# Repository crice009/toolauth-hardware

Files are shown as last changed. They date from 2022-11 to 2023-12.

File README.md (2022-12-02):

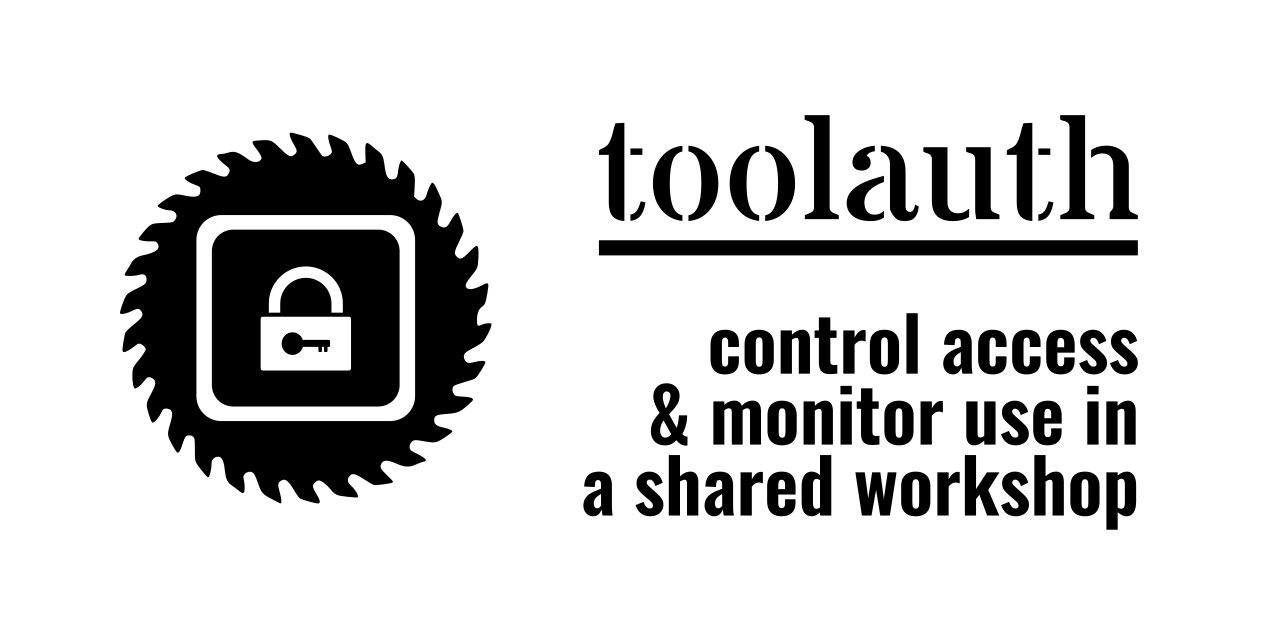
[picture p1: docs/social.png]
toolauth-logo


# toolauth-hardware
The custom PCB for the toolauth system. Intended to control access to tools (based on credentials) in a shared workshop. Designed to work with an ESP32 board and ESPHome.

Completely designed in KiCAD 6 and ordered as assembled boards from JLCPCB.

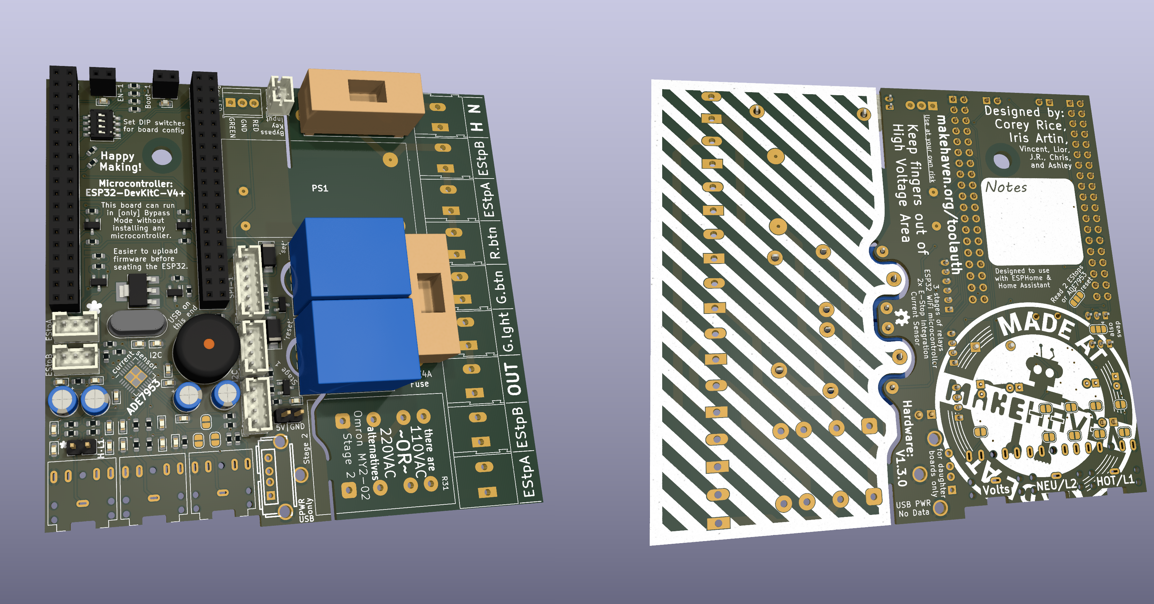
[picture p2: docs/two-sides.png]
board-examples board-renders


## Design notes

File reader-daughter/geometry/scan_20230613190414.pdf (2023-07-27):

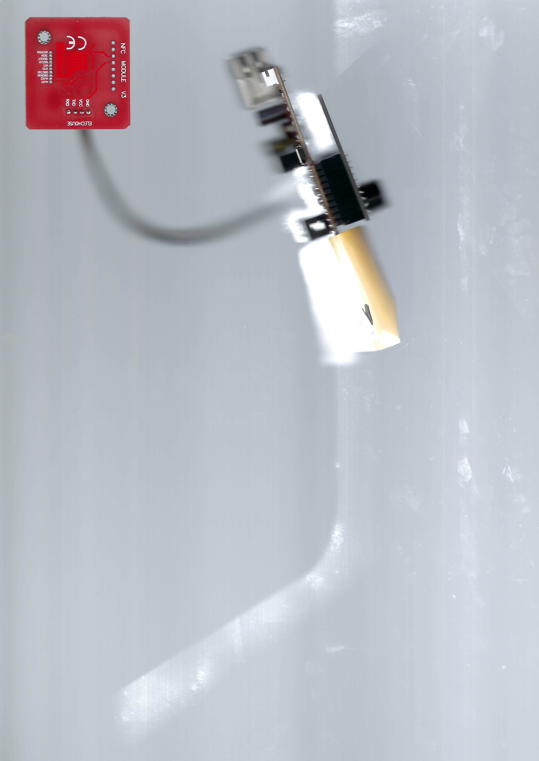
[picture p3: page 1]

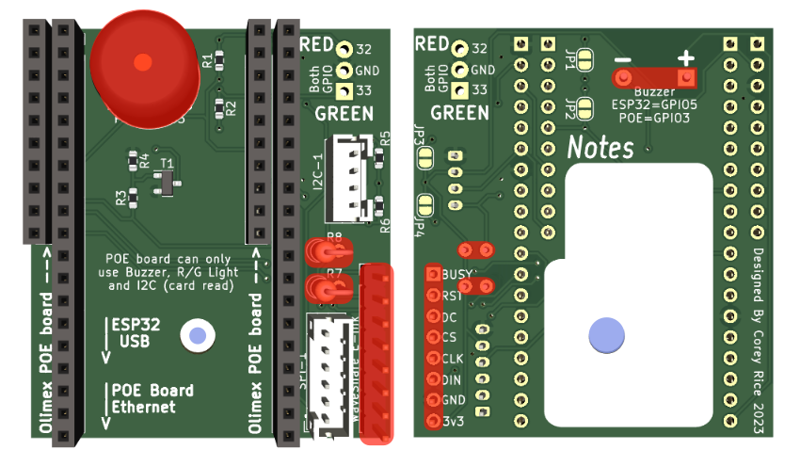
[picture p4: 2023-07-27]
docs/img/rd-design.png

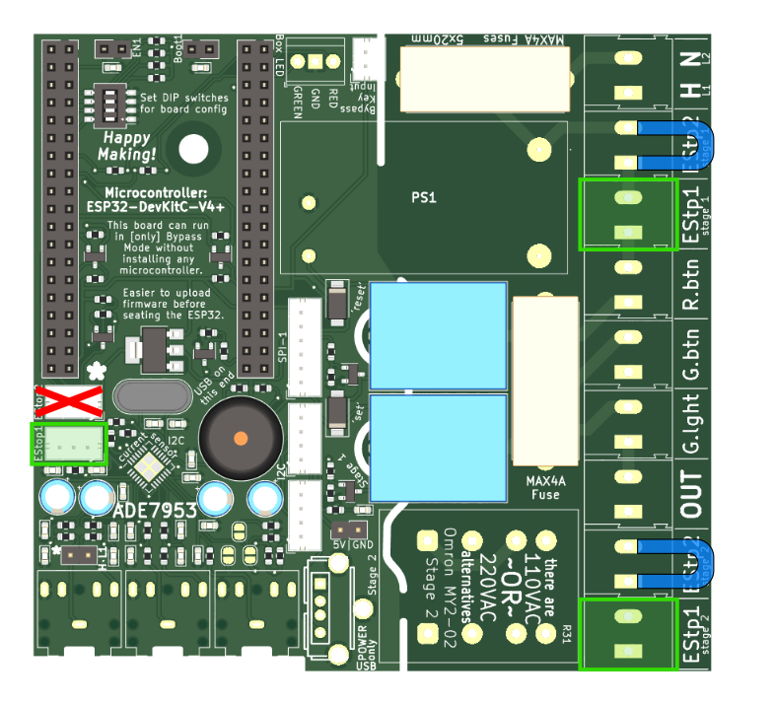
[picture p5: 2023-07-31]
docs/img/v1.3-one-estop.png

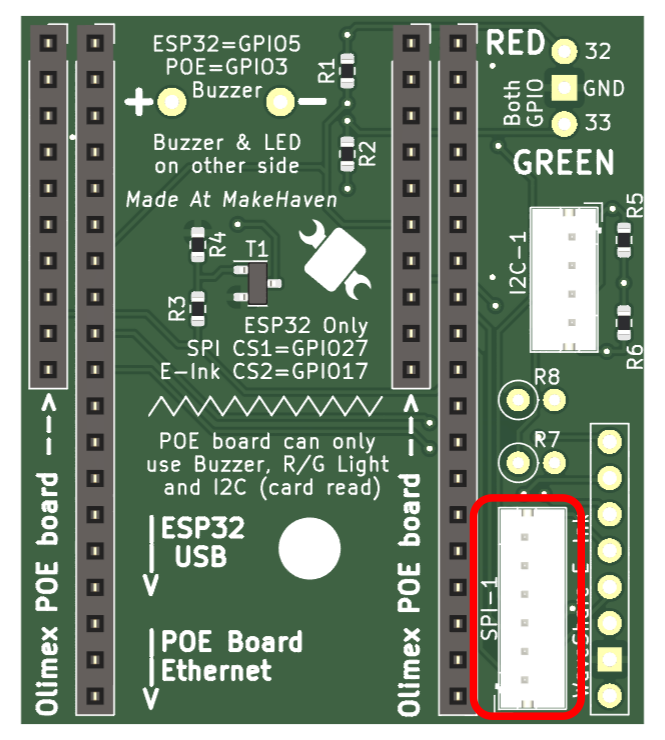
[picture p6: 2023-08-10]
docs/img/rd-spi.png

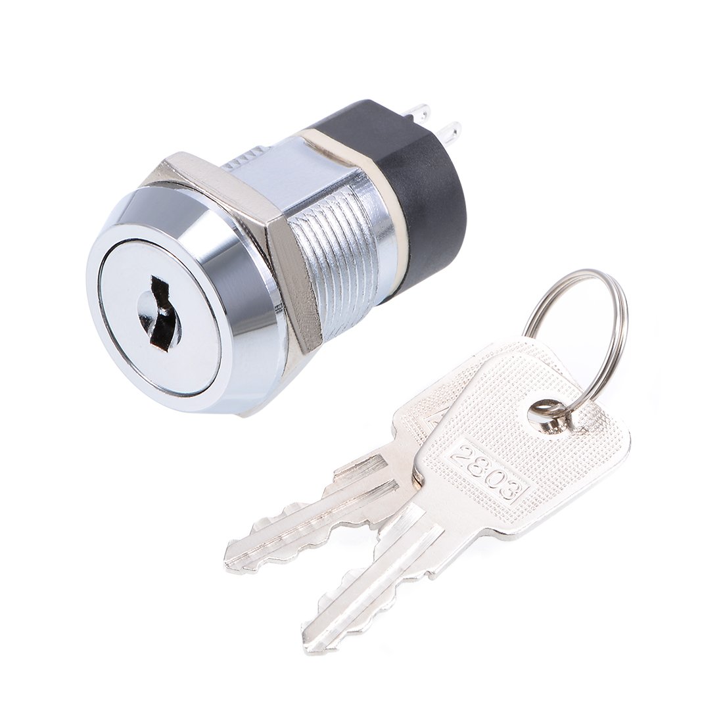
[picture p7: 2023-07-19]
docs/img/key-switch.jpg

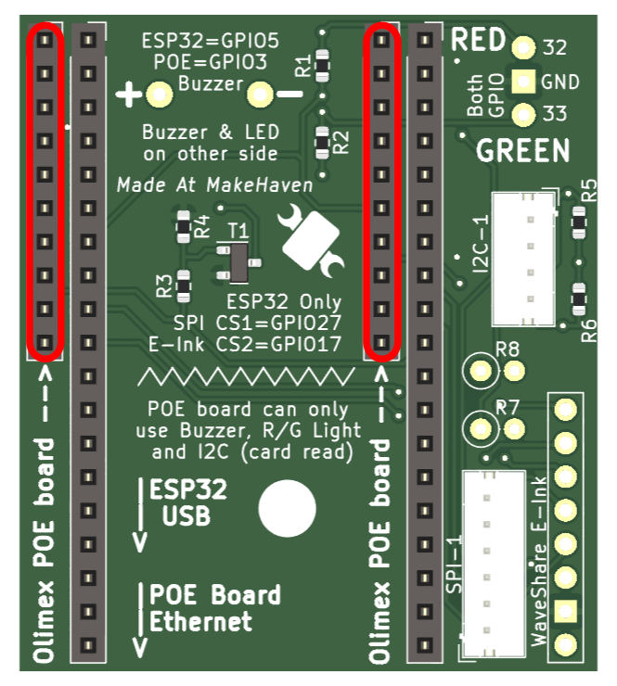
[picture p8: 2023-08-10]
docs/img/rd-poe.png

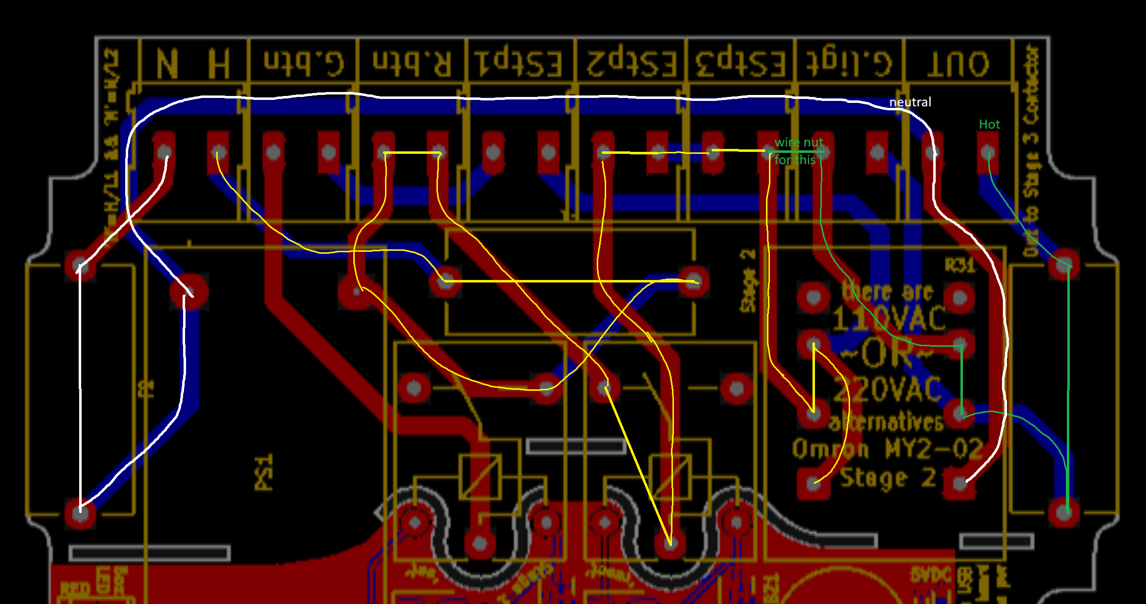
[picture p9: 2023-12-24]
docs/img/b1p2-gerber-markup.png

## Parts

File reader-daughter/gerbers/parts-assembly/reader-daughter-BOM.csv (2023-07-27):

Comment | Designator | Footprint | JLCPCB Part #
Conn_01x04_Female | I2C-1 | JST_PH_B4B-PH-K_1x04_P2.00mm_Vertical | C131334
1k | R2,R3,R1 | R_0603_1608Metric | C21190
Conn_01x06_Female | SPI-1 | JST_PH_B6B-PH-K_1x06_P2.00mm_Vertical | C131342
Conn_01x10_Female | J2,J1 | PinSocket_1x10_P2.54mm_Vertical | C358723
2.2k | R6,R5 | R_0603_1608Metric | C4190
Conn_01x19_Female | J6,J5 | PinSocket_1x19_P2.54mm_Vertical | C2897382
AO3400A | T1 | SOT-23 | C427382
10k | R4 | R_0603_1608Metric | C25804

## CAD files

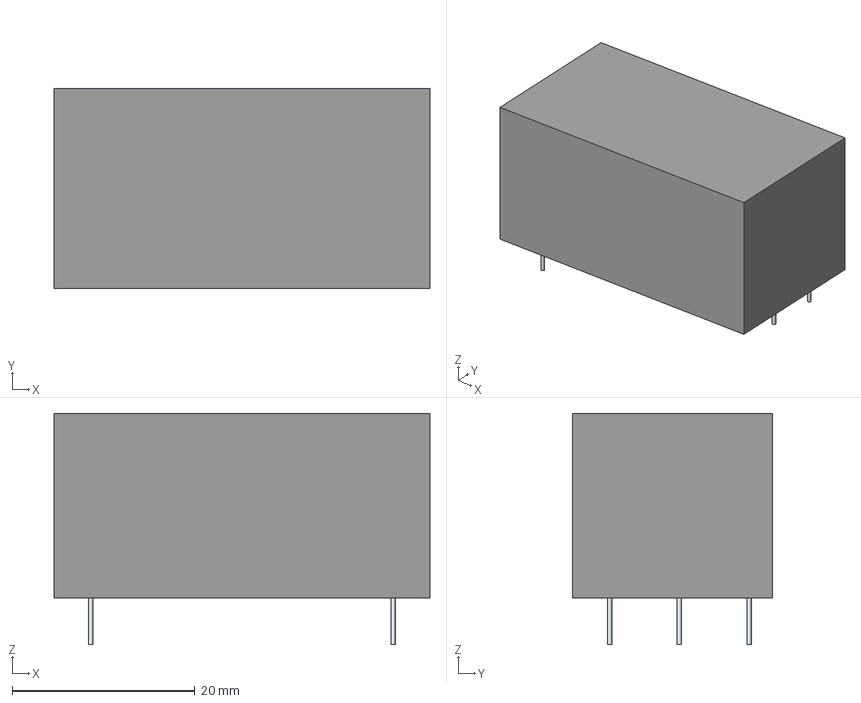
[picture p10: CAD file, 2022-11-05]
V1.3/odd-parts/CFM06S050-E-Cincon/CFM06S050-E.stp
41.1 x 21.8 x 25.3 mm
Leads x 4

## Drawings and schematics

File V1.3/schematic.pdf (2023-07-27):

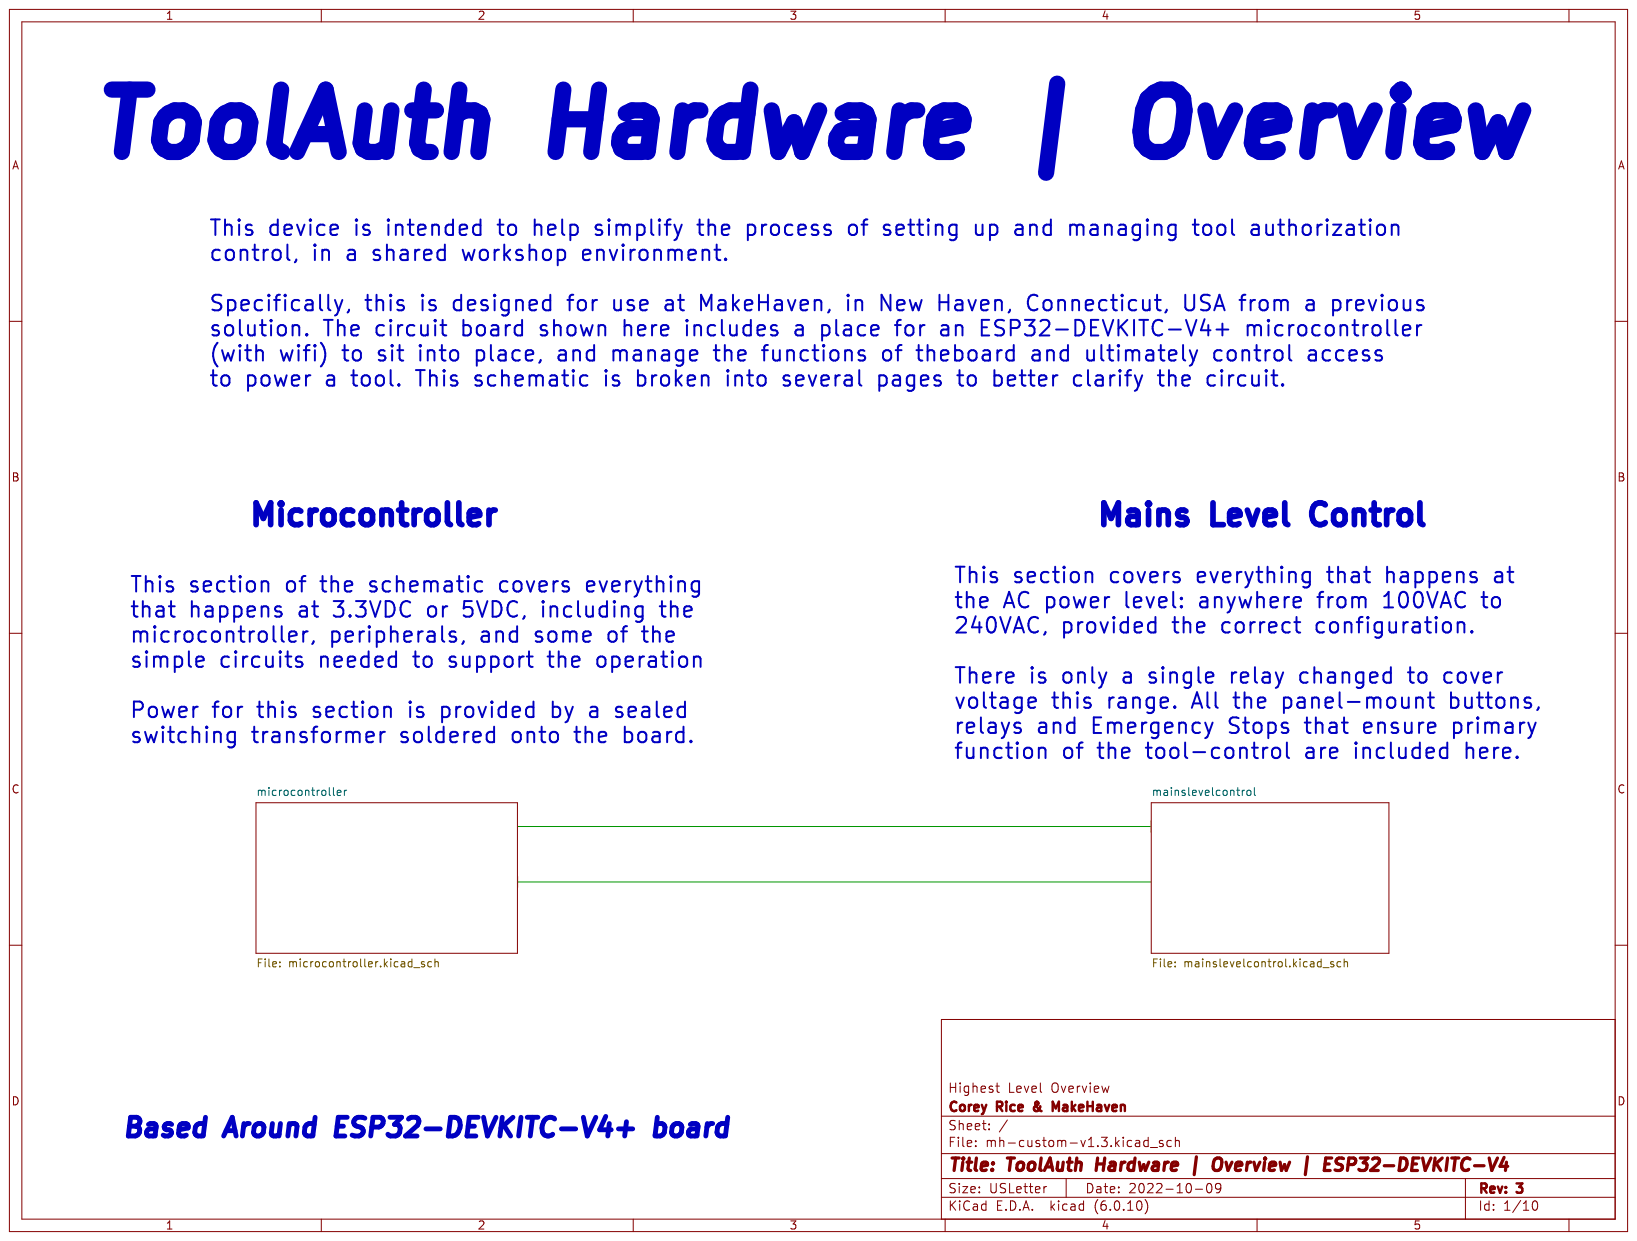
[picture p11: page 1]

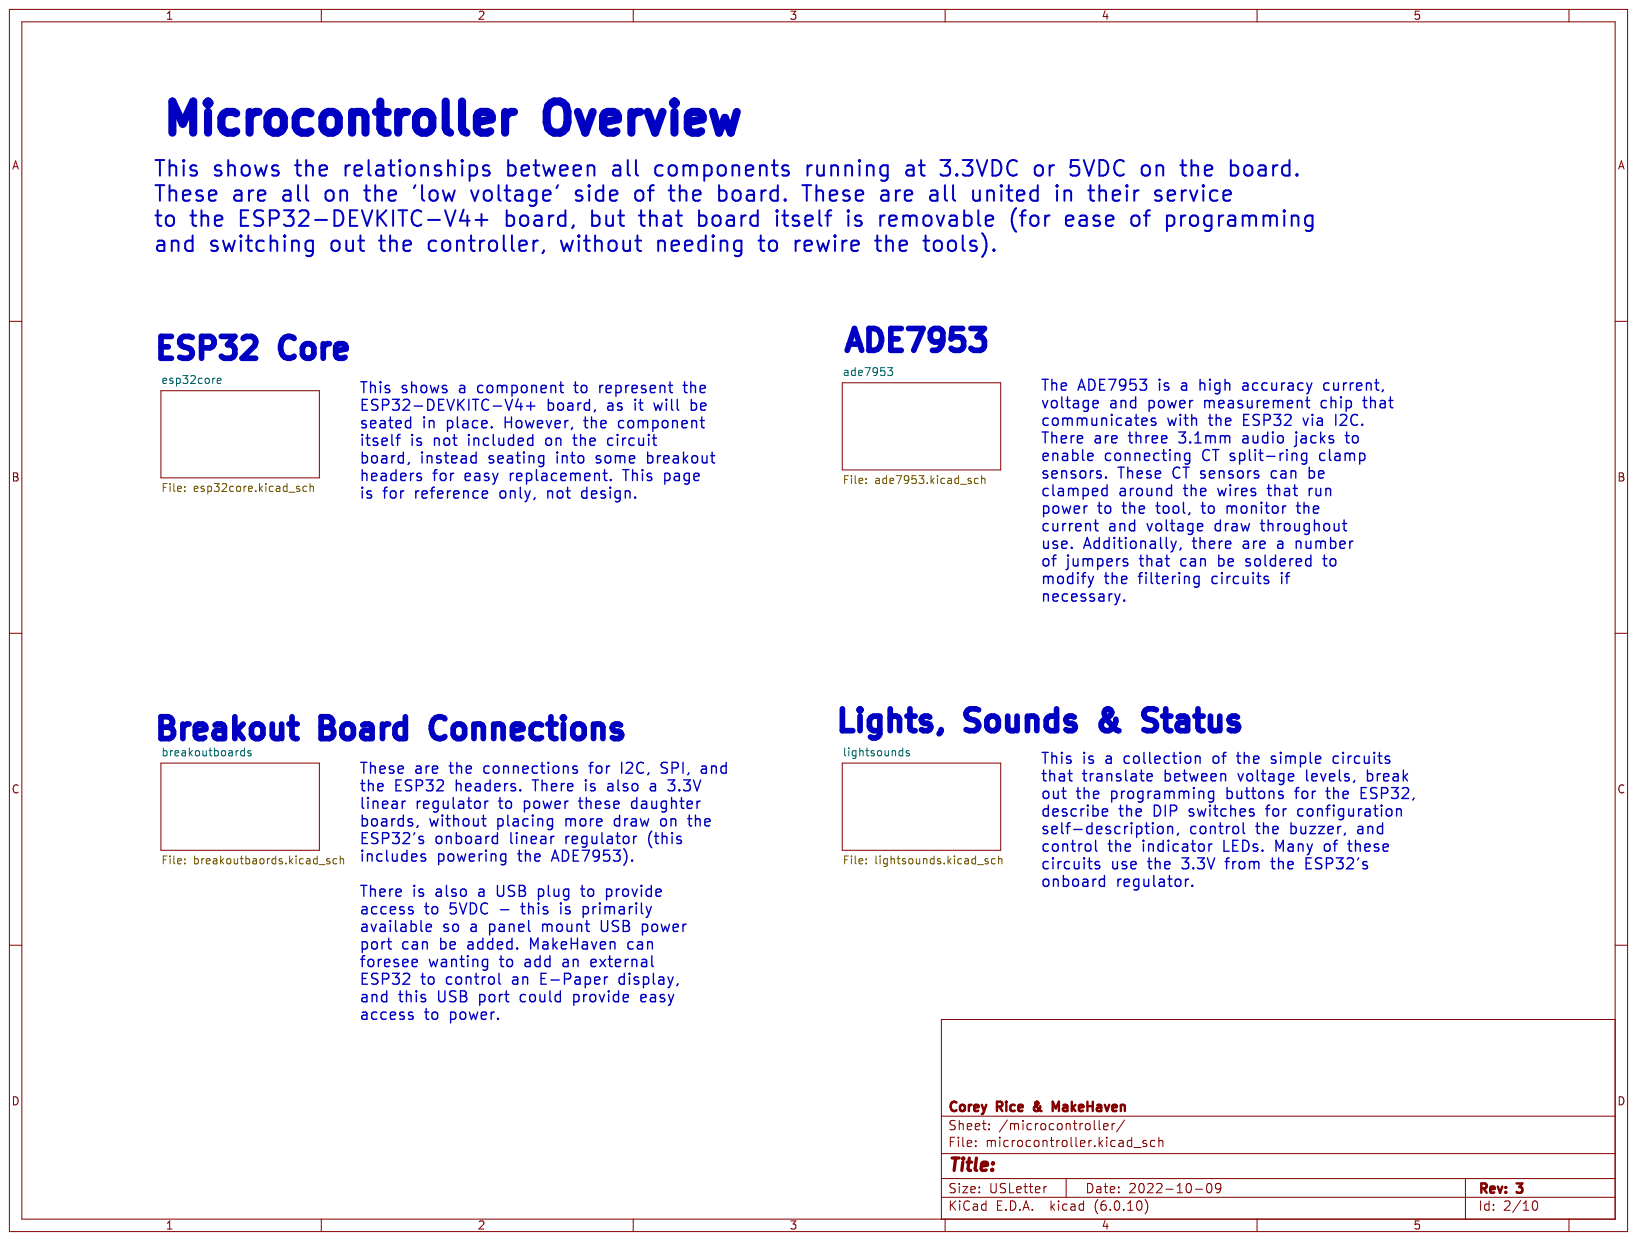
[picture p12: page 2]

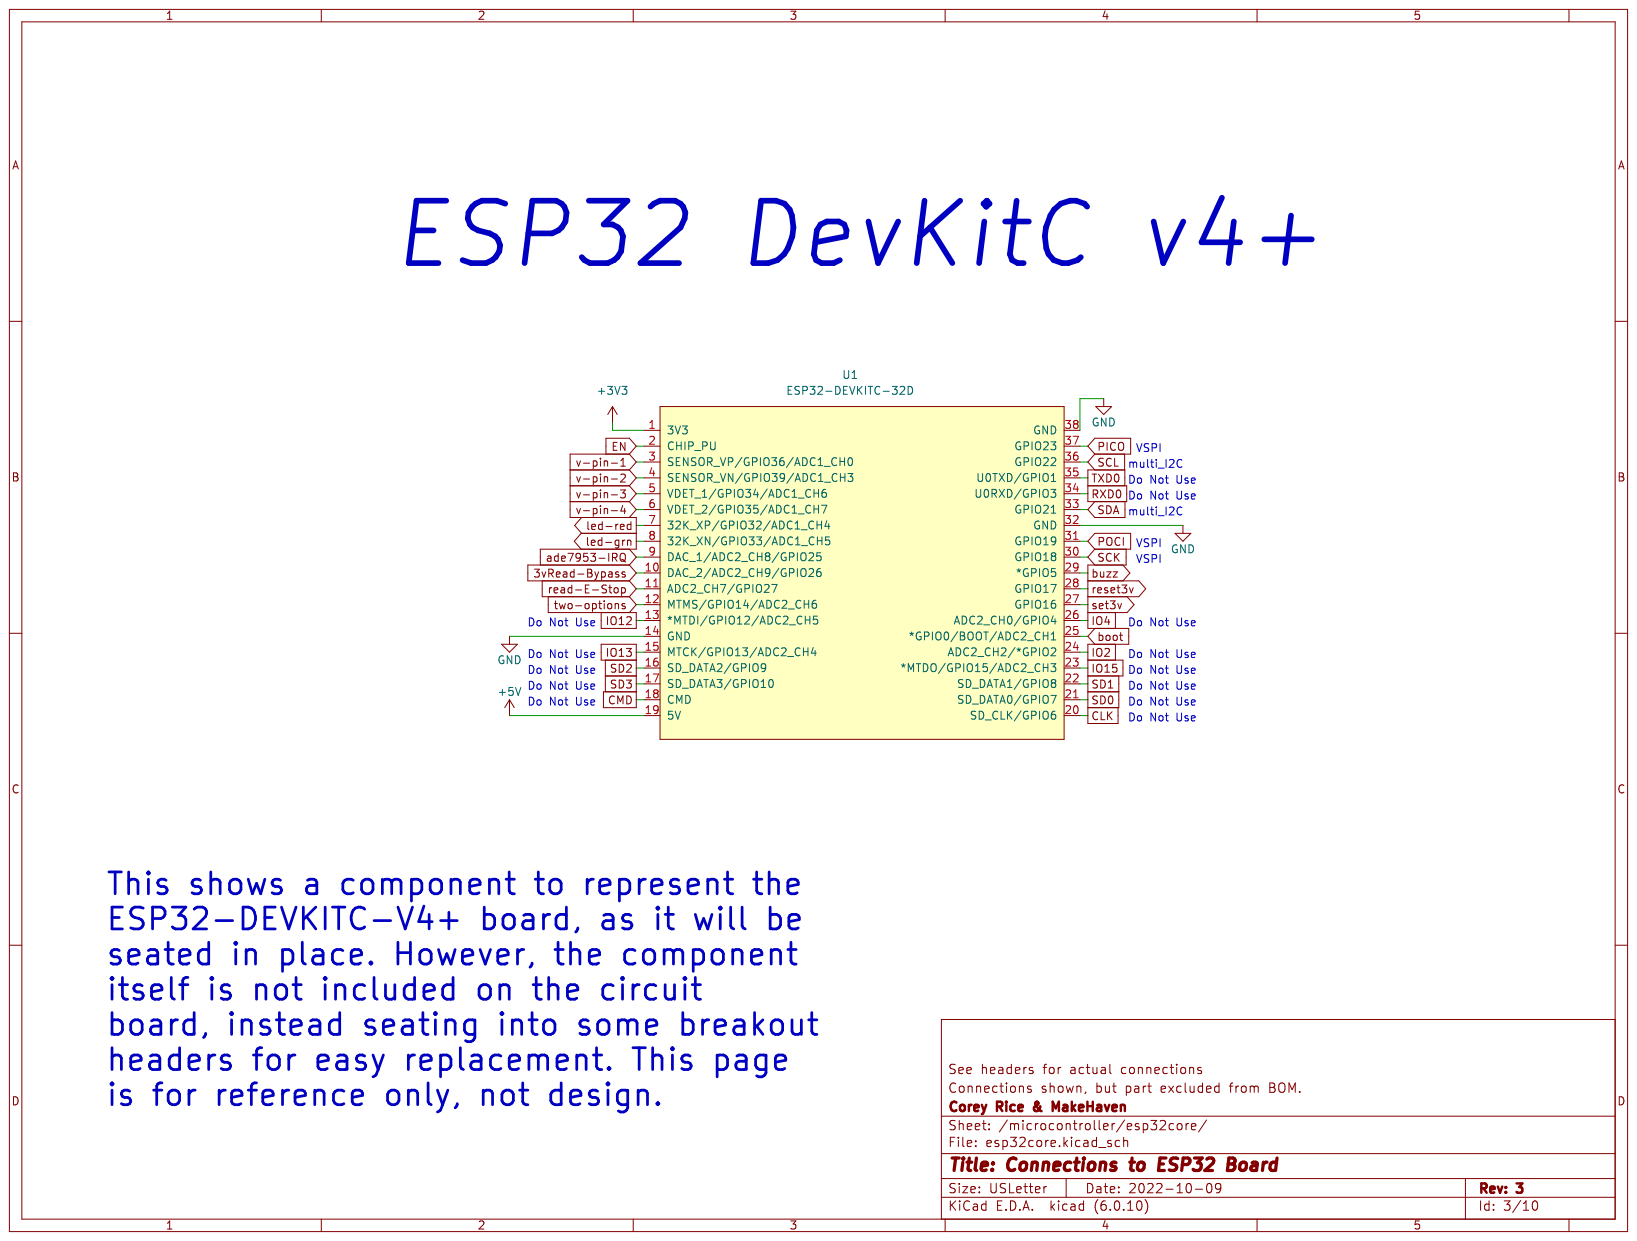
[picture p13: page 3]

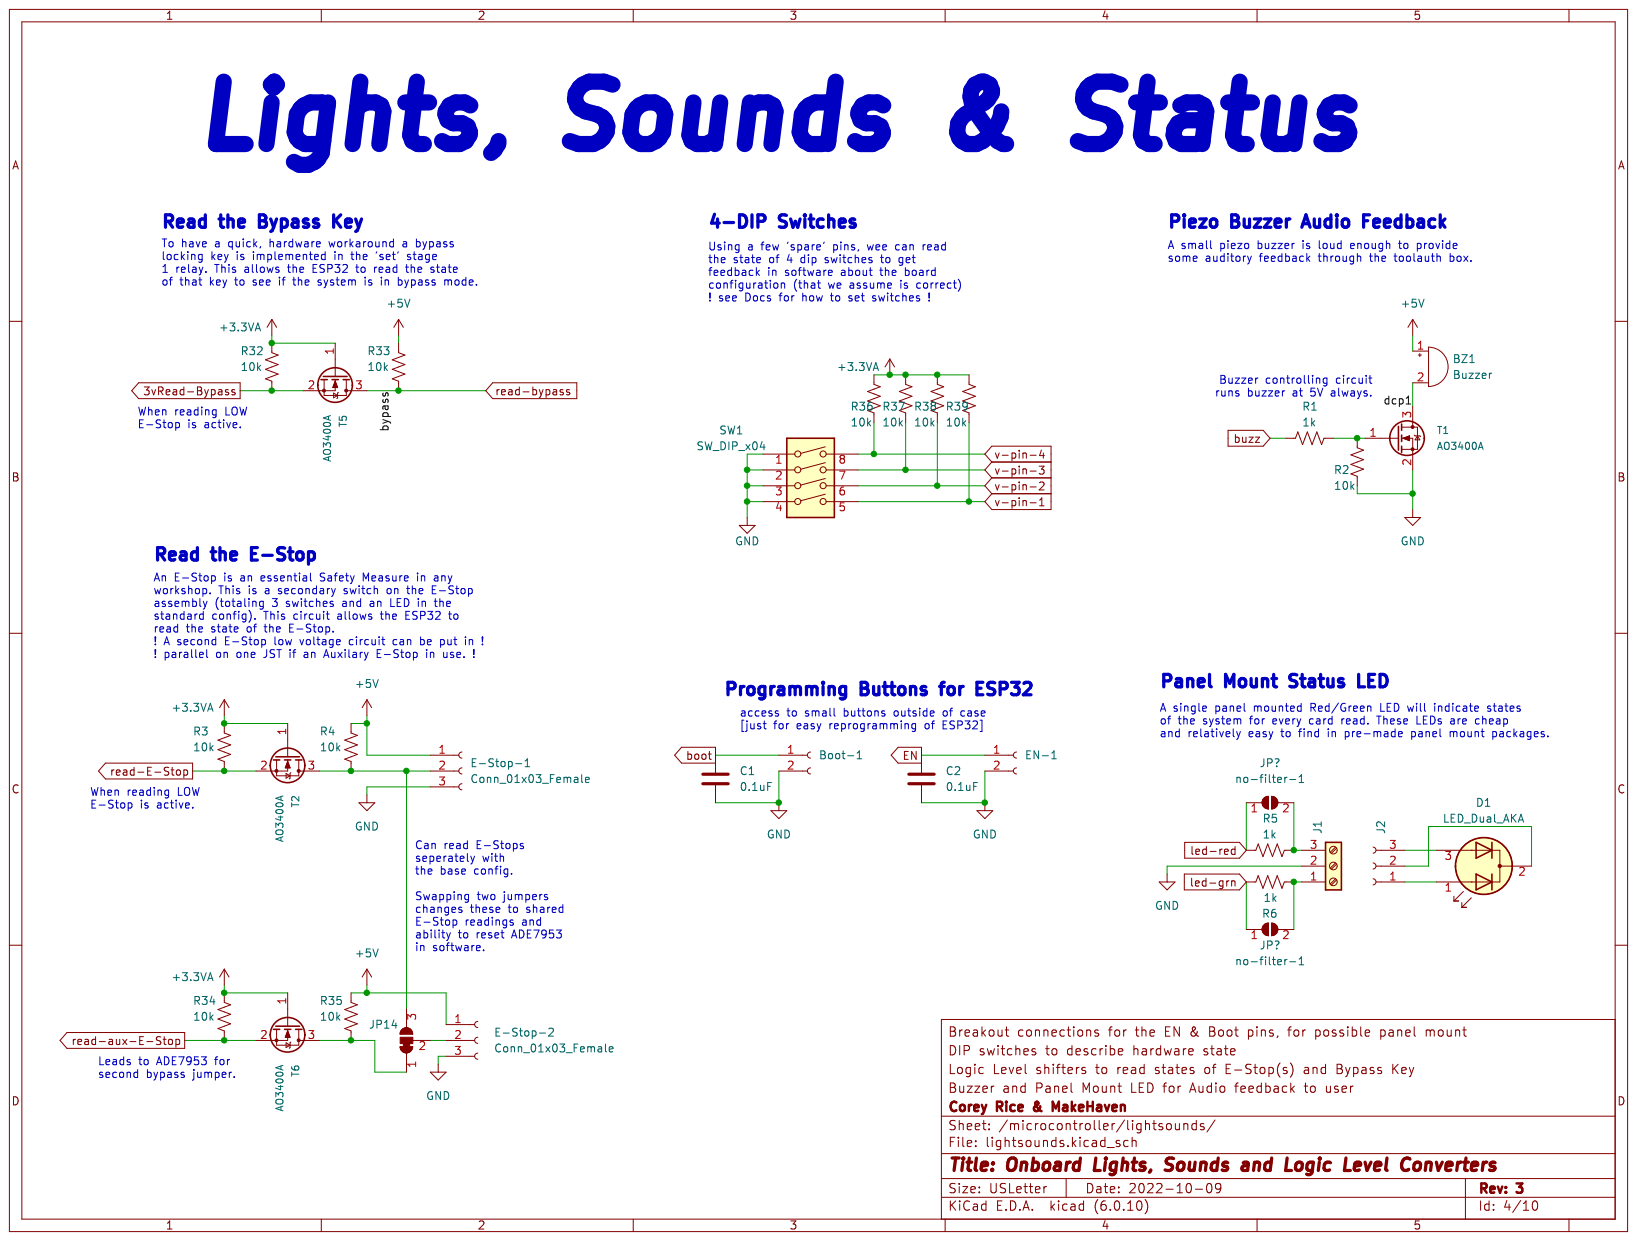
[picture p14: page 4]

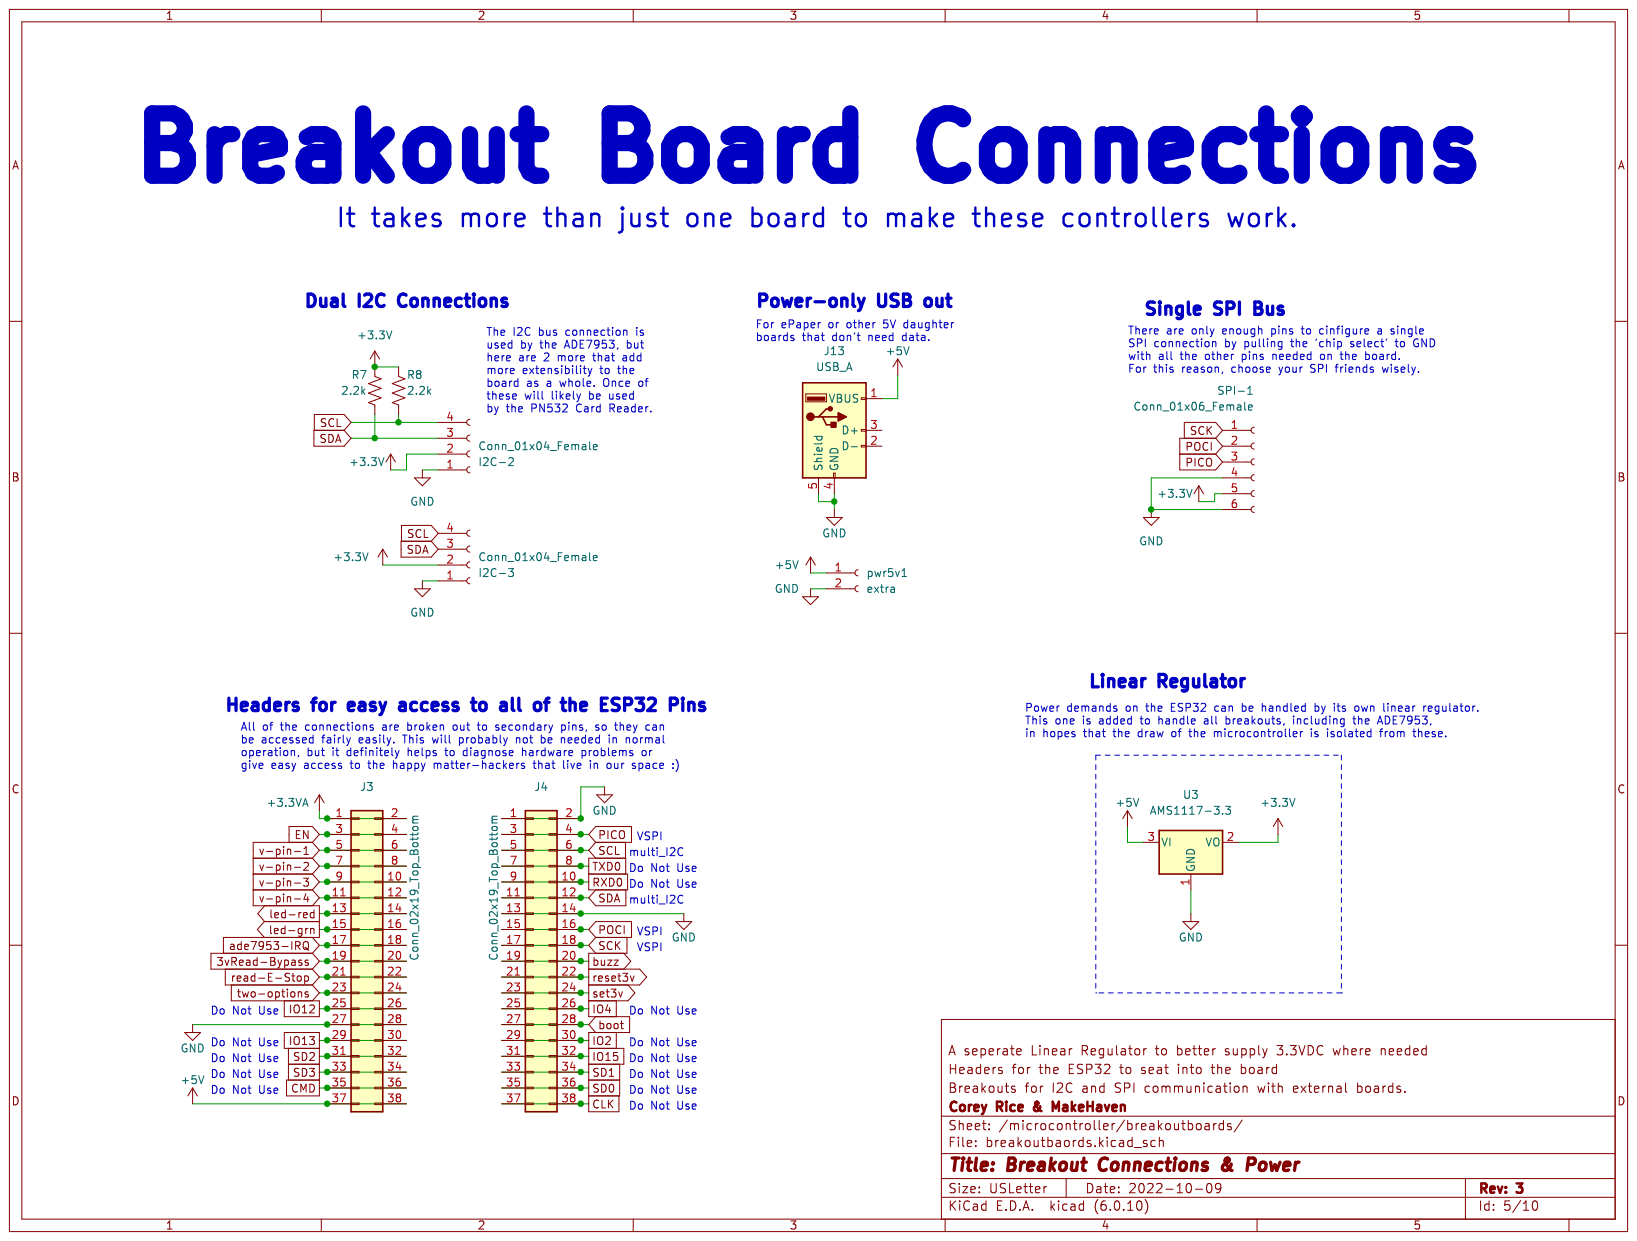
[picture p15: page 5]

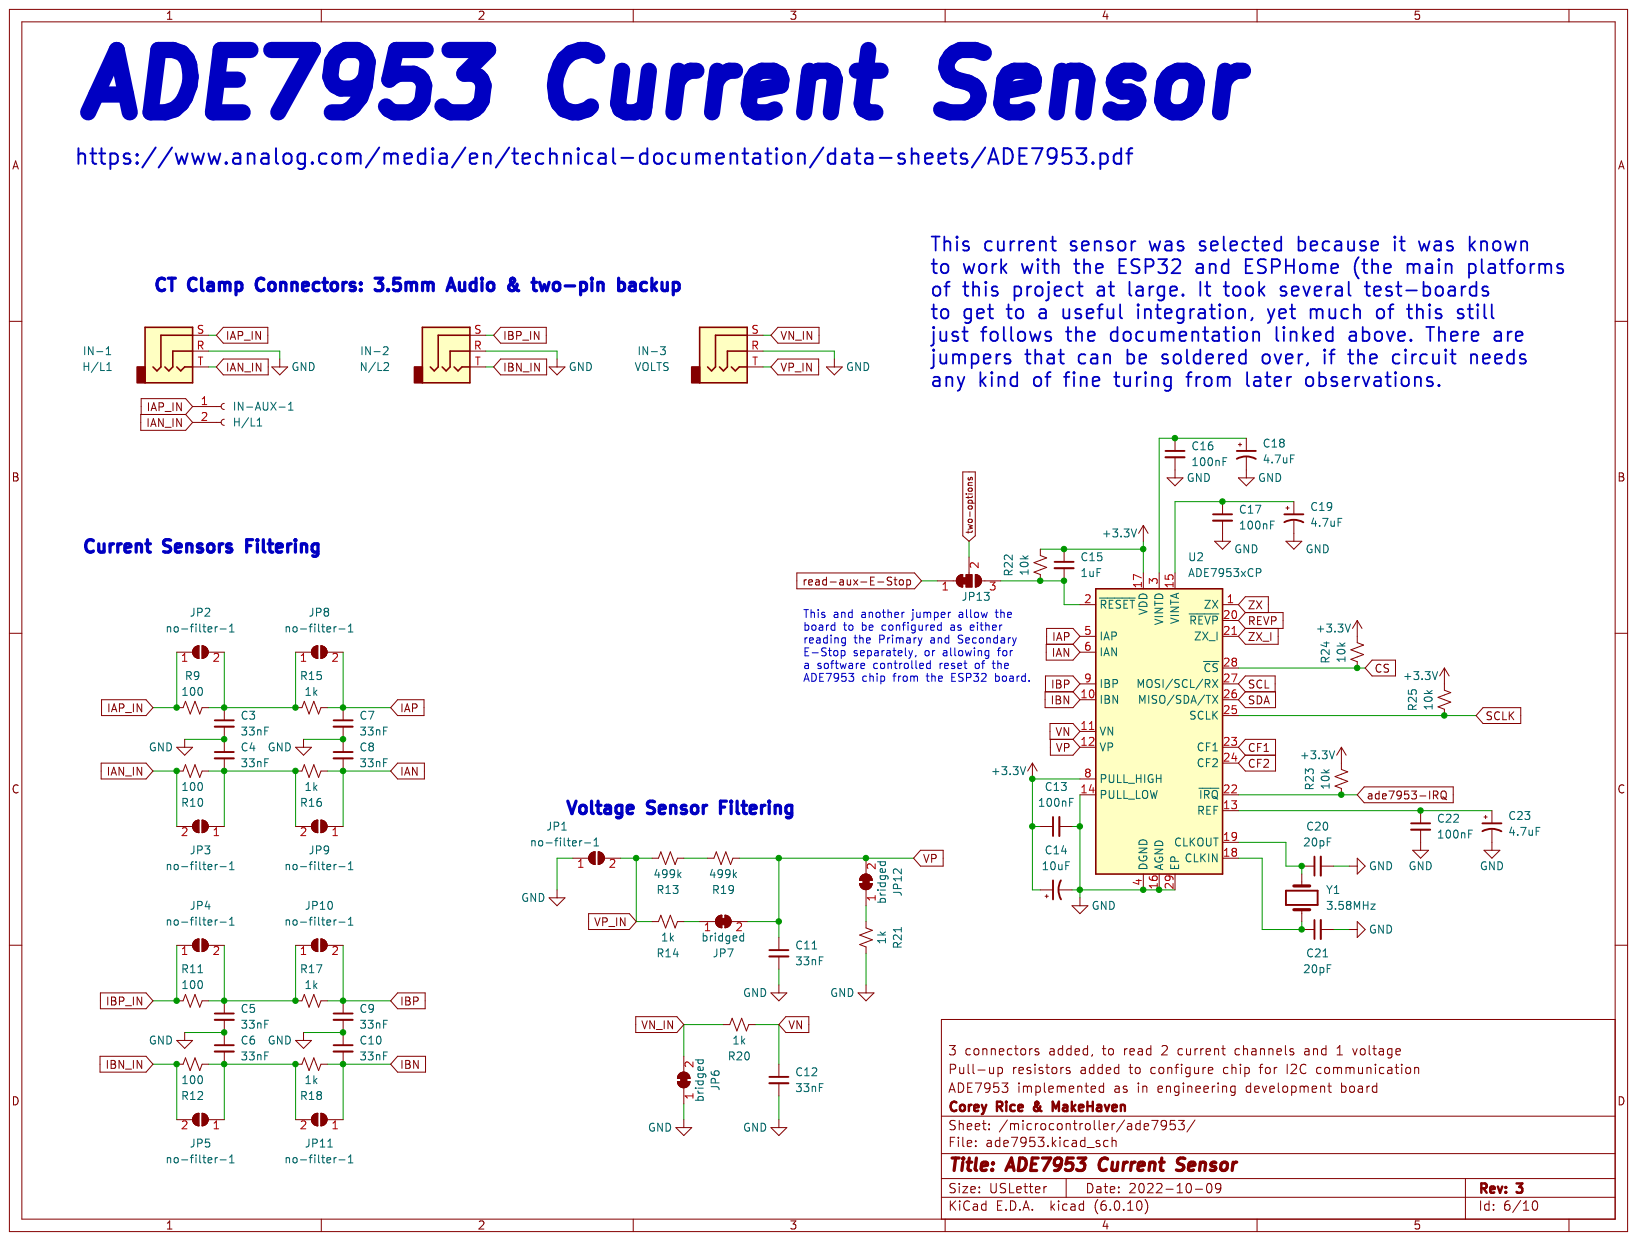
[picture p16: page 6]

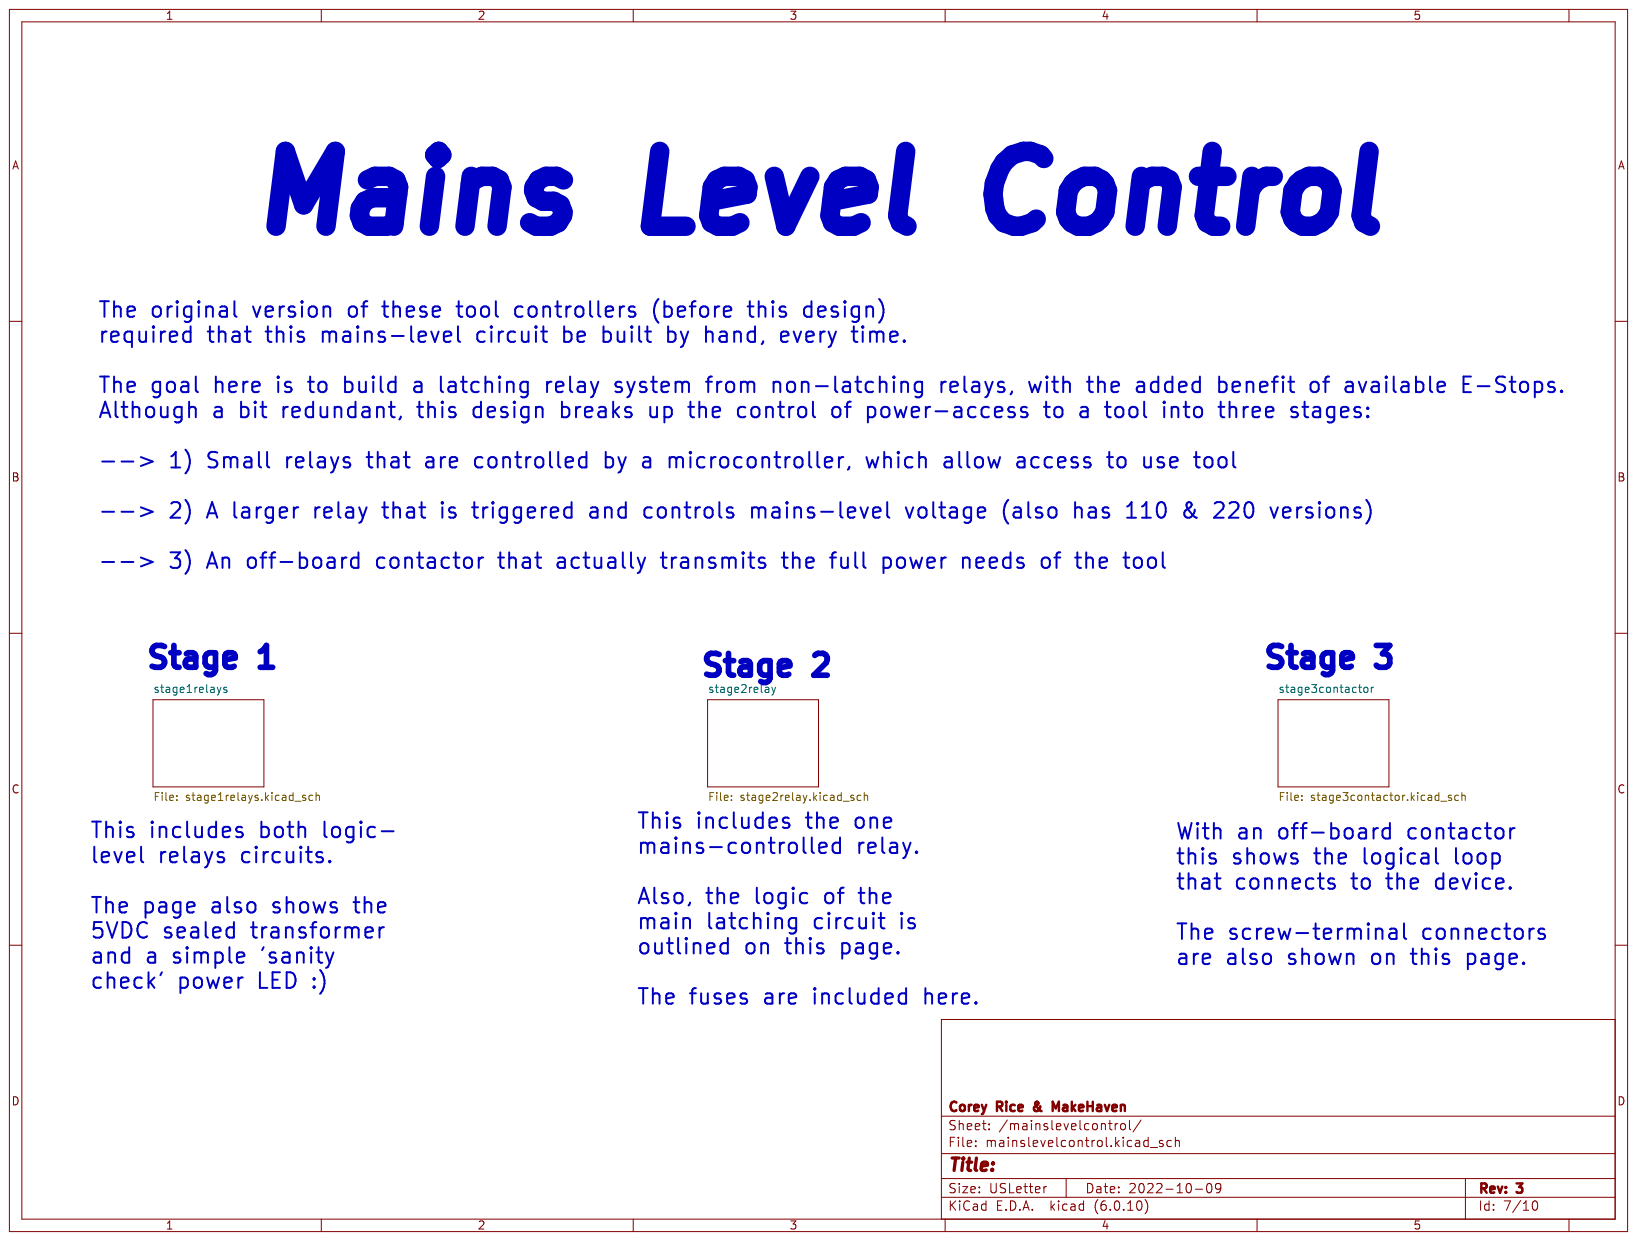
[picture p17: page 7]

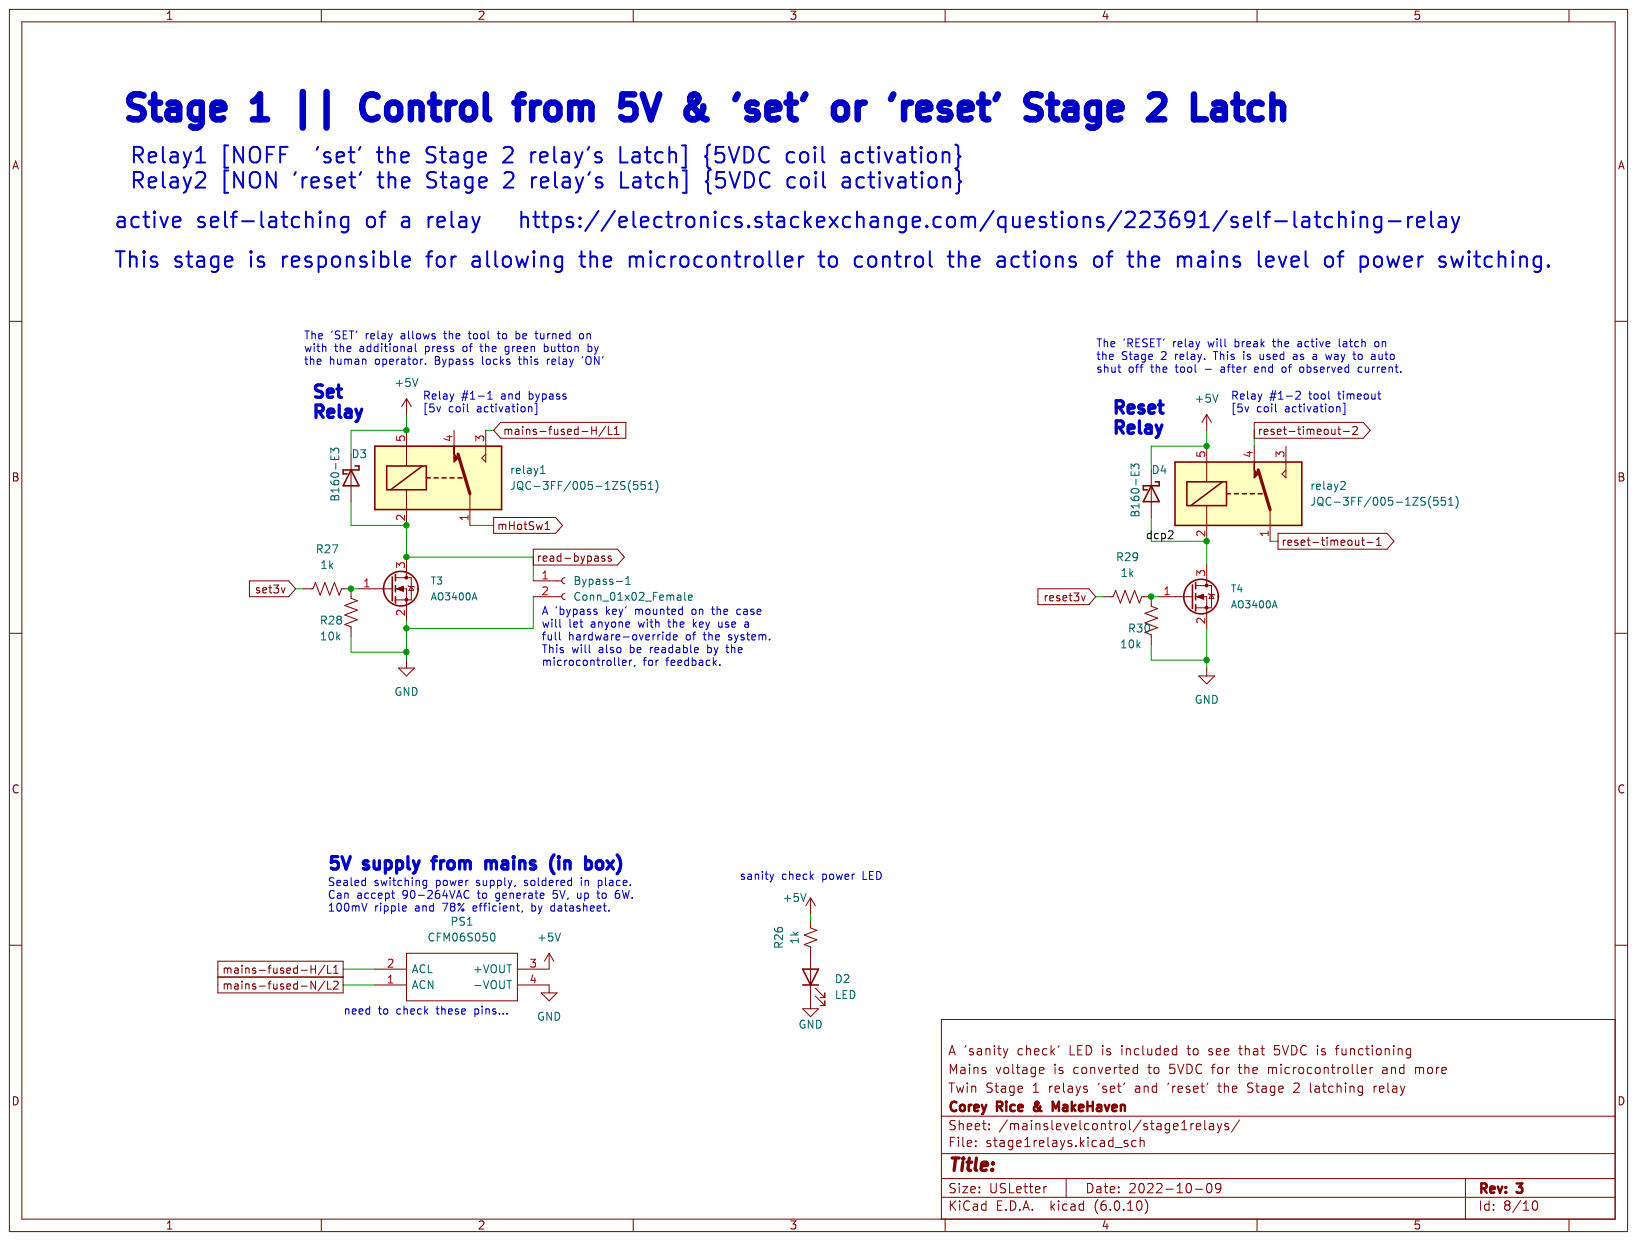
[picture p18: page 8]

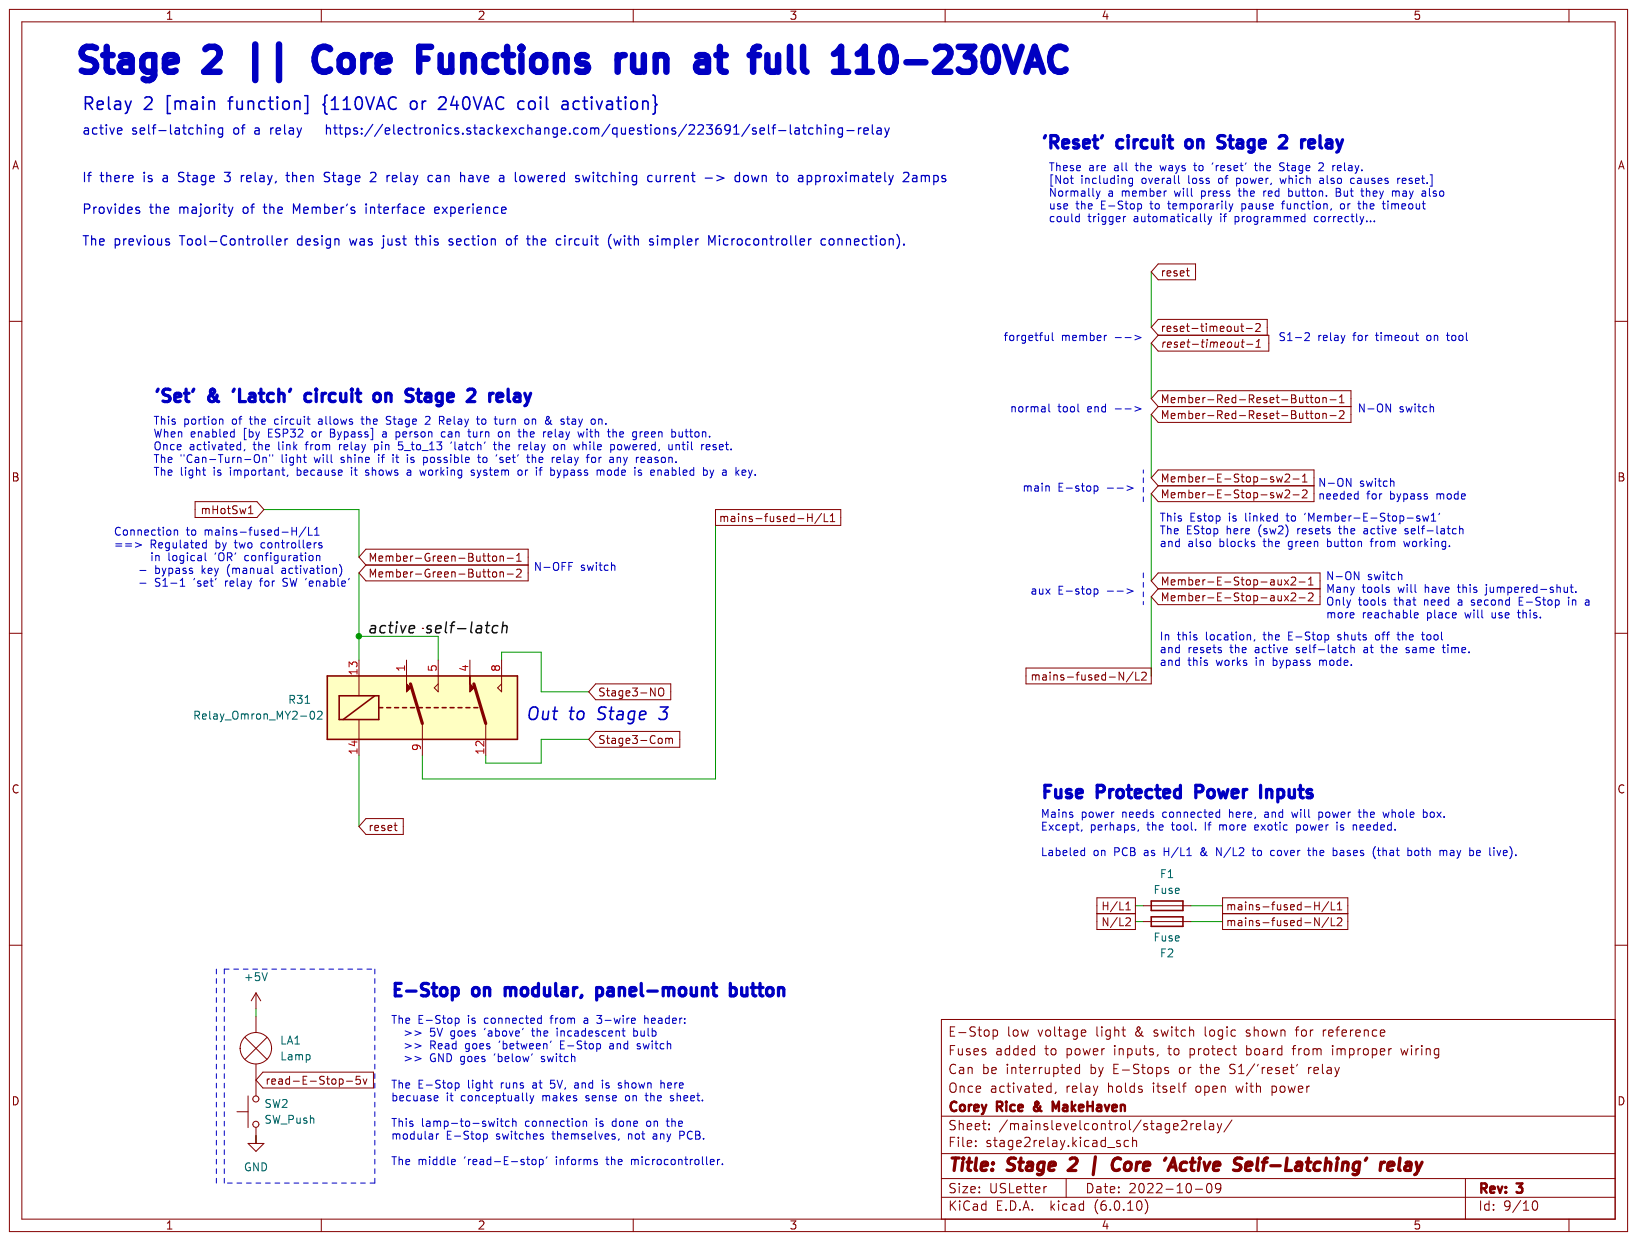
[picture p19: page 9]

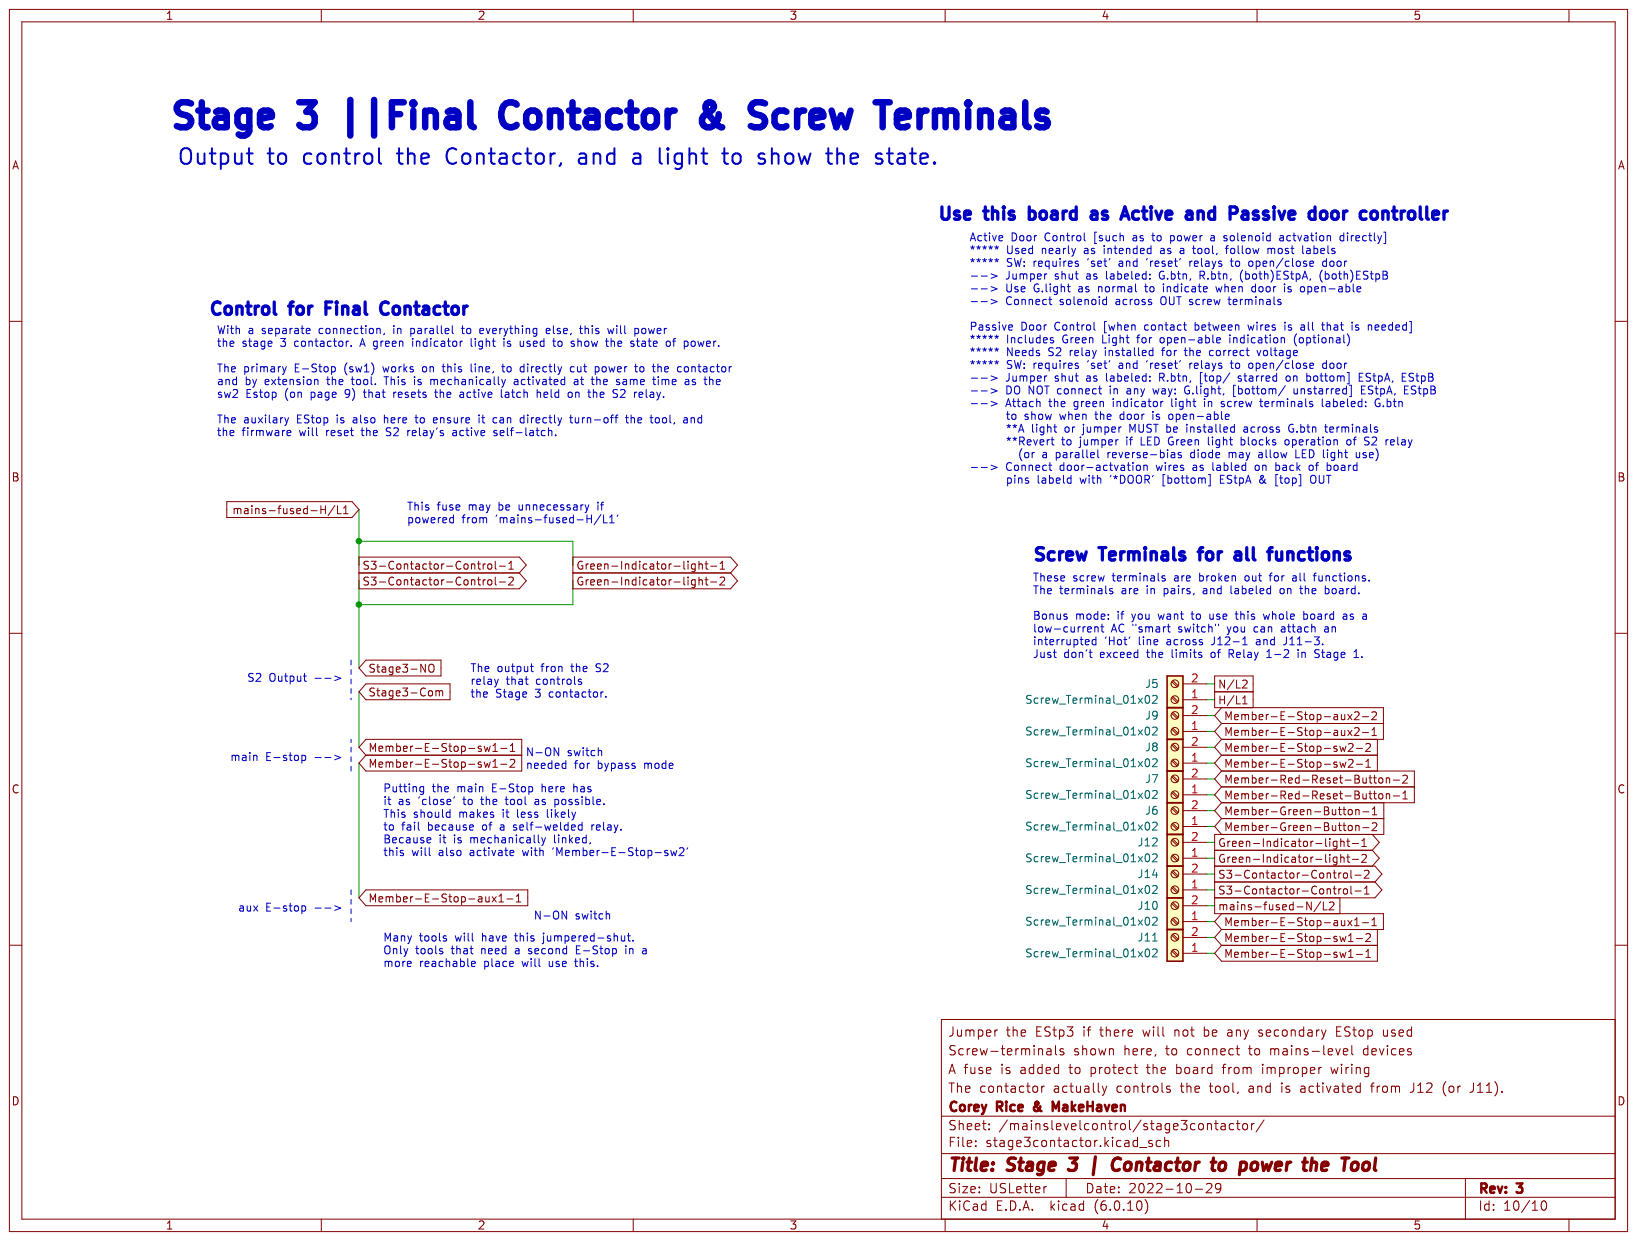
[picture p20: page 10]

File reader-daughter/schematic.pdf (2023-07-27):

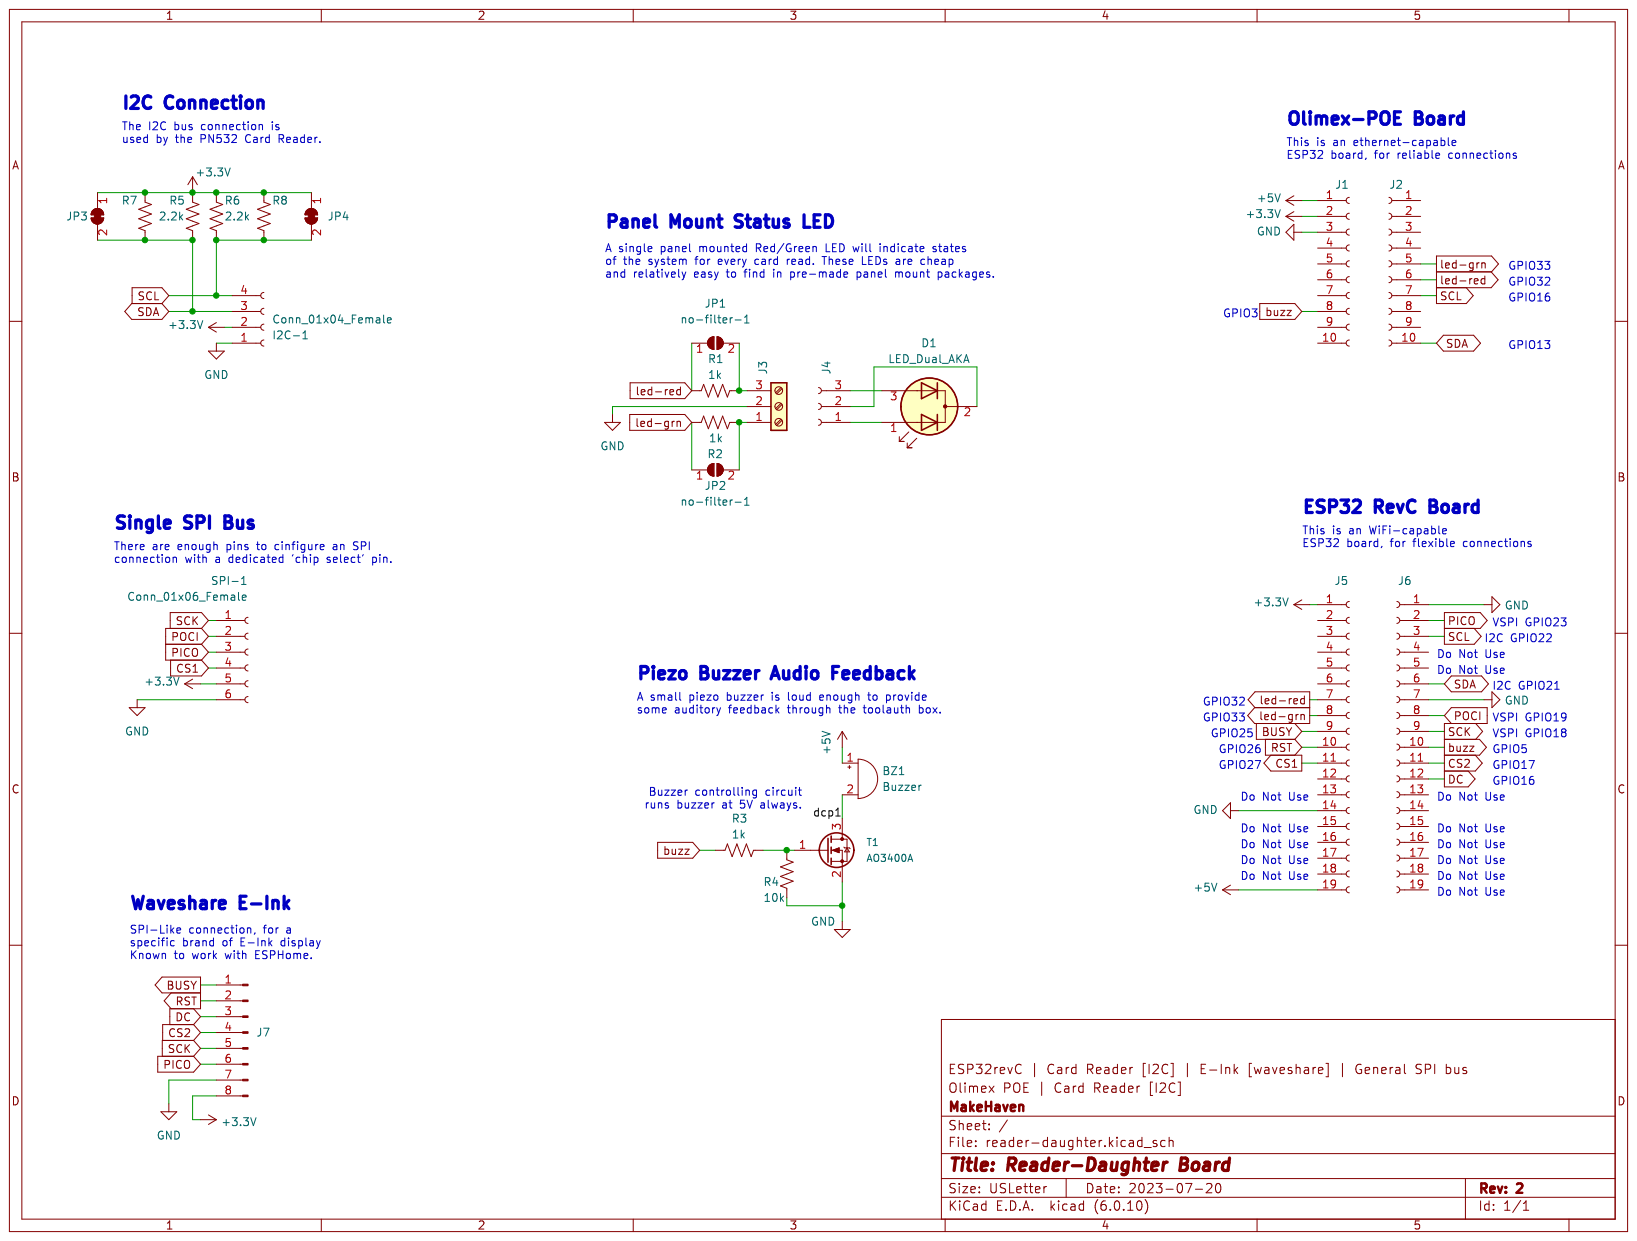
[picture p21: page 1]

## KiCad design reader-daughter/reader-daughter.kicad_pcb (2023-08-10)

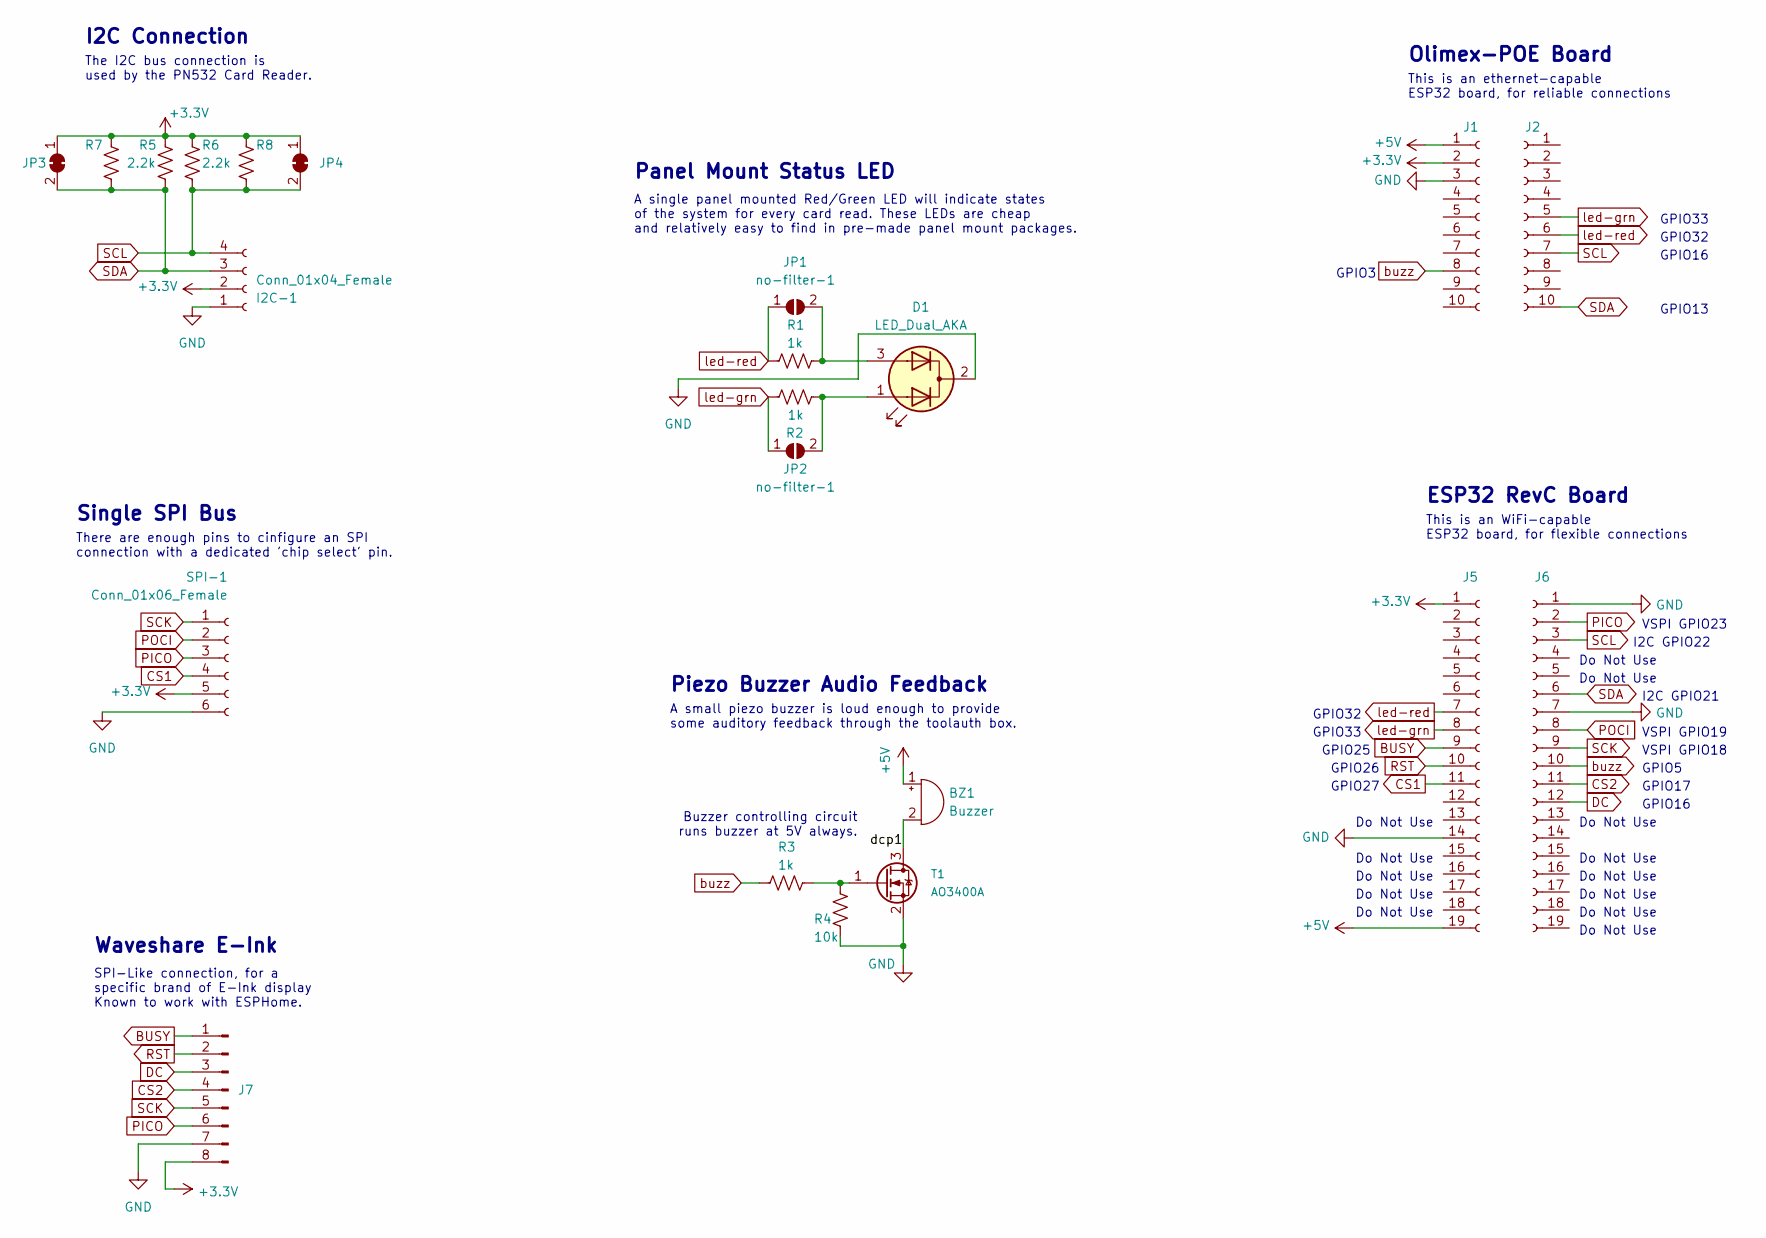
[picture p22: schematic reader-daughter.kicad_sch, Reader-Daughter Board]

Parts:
BZ1: Buzzer; Buzzer_12x9.5RM7.6; JLCPCB Part # C96095
D1: LED_Dual_AKA; LED_D5.0mm-3
I2C-1: Conn_01x04_Female; JST_PH_B4B-PH-K_1x04_P2.00mm_Vertical; JLCPCB Part # C131334
J1, J2: Conn_01x10_Female; PinSocket_1x10_P2.54mm_Vertical; JLCPCB Part # C2938384
J5, J6: Conn_01x19_Female; PinSocket_1x19_P2.54mm_Vertical; JLCPCB Part # C2906049
J7: Conn_01x08_Male; PinHeader_1x08_P2.54mm_Vertical
JP1, JP2: no-filter-1; SolderJumper-2_P1.3mm_Open_RoundedPad1.0x1.5mm
JP3, JP4: SolderJumper_2_Bridged; SolderJumper-2_P1.3mm_Bridged_RoundedPad1.0x1.5mm
R1, R2, R3: 1k; R_0603_1608Metric; JLCPCB Part # C21190
R4: 10k; R_0603_1608Metric; JLCPCB Part # C25804
R5, R6: 2.2k; R_0603_1608Metric; JLCPCB Part # C4190
R7, R8: 2.2k; R_Axial_DIN0207_L6.3mm_D2.5mm_P2.54mm_Vertical; JLCPCB Part # C4190
SPI-1: Conn_01x06_Female; JST_PH_B6B-PH-K_1x06_P2.00mm_Vertical; JLCPCB Part # C131342
T1: AO3400A; SOT-23; JLCPCB Part # C427382

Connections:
+3V3: I2C-1.2, J1.2, J5.1, J7.8, JP3.1 (A), JP4.1 (A), R5.2, R6.2, R7.2, R8.2, SPI-1.5
+5V: BZ1.1 (-), J1.1, J5.19
/dcp1: BZ1.2 (+), T1.3 (D)
BUSY: J5.9, J7.1
CS1: J5.11, SPI-1.4
CS2: J6.11, J7.4
DC: J6.12, J7.3
GND: D1.2 (K), I2C-1.1, J1.3, J5.14, J6.1, J6.7, J7.7, R4.1, SPI-1.6, T1.2 (S); also elsewhere on the board
unnamed: D1.3 (A2), JP1.2 (B), R1.2
unnamed: D1.1 (A1), JP2.2 (B), R2.1
unnamed: R3.2, R4.2, T1.1 (G)
PICO: J6.2, J7.6, SPI-1.3
POCI: J6.8, SPI-1.2
RST: J5.10, J7.2
SCK: J6.9, J7.5, SPI-1.1
SCL: I2C-1.4, J2.7, J6.3, JP4.2 (B), R6.1, R8.1
SDA: I2C-1.3, J2.10, J6.6, JP3.2 (B), R5.1, R7.1
buzz: J1.8, J6.10, R3.1
led-grn: J2.5, J5.8, JP2.1 (A), R2.2
led-red: J2.6, J5.7, JP1.1 (A), R1.1

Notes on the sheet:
Do Not Use
GPIO5
VSPI GPIO19
A single panel mounted Red/Green LED will indicate states of the system for every card read. These LEDs are cheap and relatively easy to find in pre-made panel mount packages.
I2C GPIO21
VSPI GPIO18
GPIO33
This is an ethernet-capable ESP32 board, for reliable connections
GPIO17
Single SPI Bus
There are enough pins to cinfigure an SPI connection with a dedicated 'chip select' pin.
GPIO32
VSPI GPIO23
GPIO3
Piezo Buzzer Audio Feedback
Buzzer controlling circuit runs buzzer at 5V always.
ESP32 RevC Board
GPIO13
GPIO26
This is an WiFi-capable ESP32 board, for flexible connections
GPIO16
GPIO25
Panel Mount Status LED
Olimex-POE Board
I2C GPIO22
Waveshare E-Ink
The I2C bus connection is used by the PN532 Card Reader.
A small piezo buzzer is loud enough to provide some auditory feedback through the toolauth box.
I2C Connection
GPIO27
SPI-Like connection, for a specific brand of E-Ink display Known to work with ESPHome.

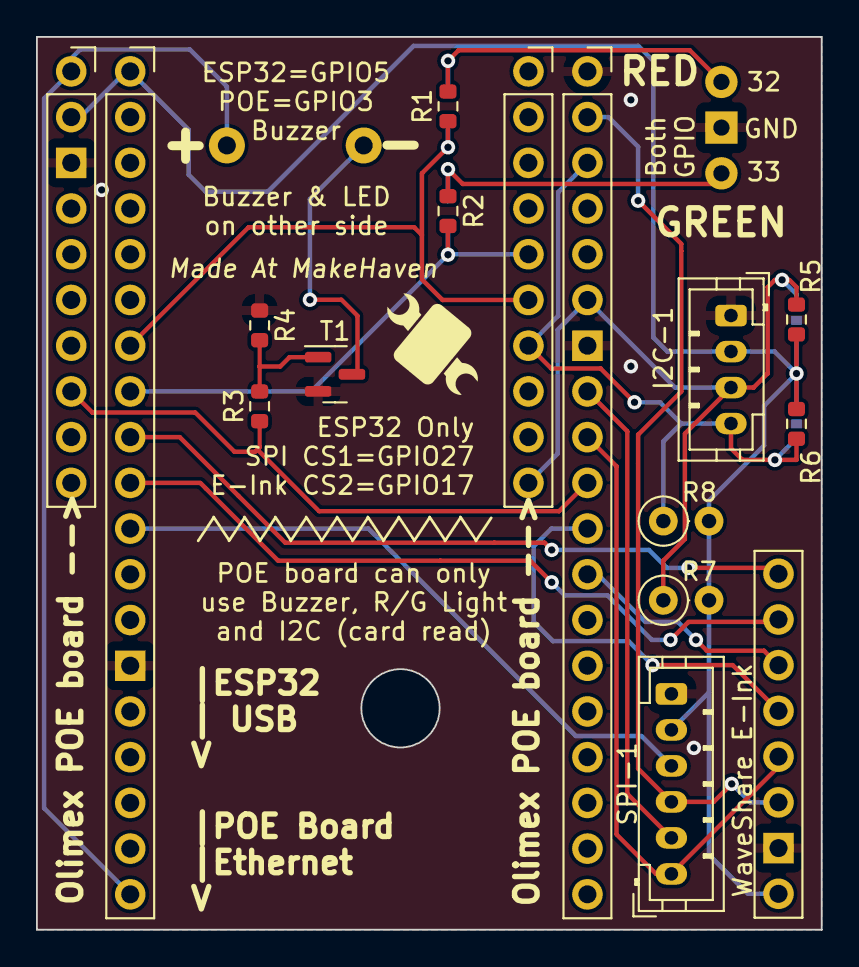
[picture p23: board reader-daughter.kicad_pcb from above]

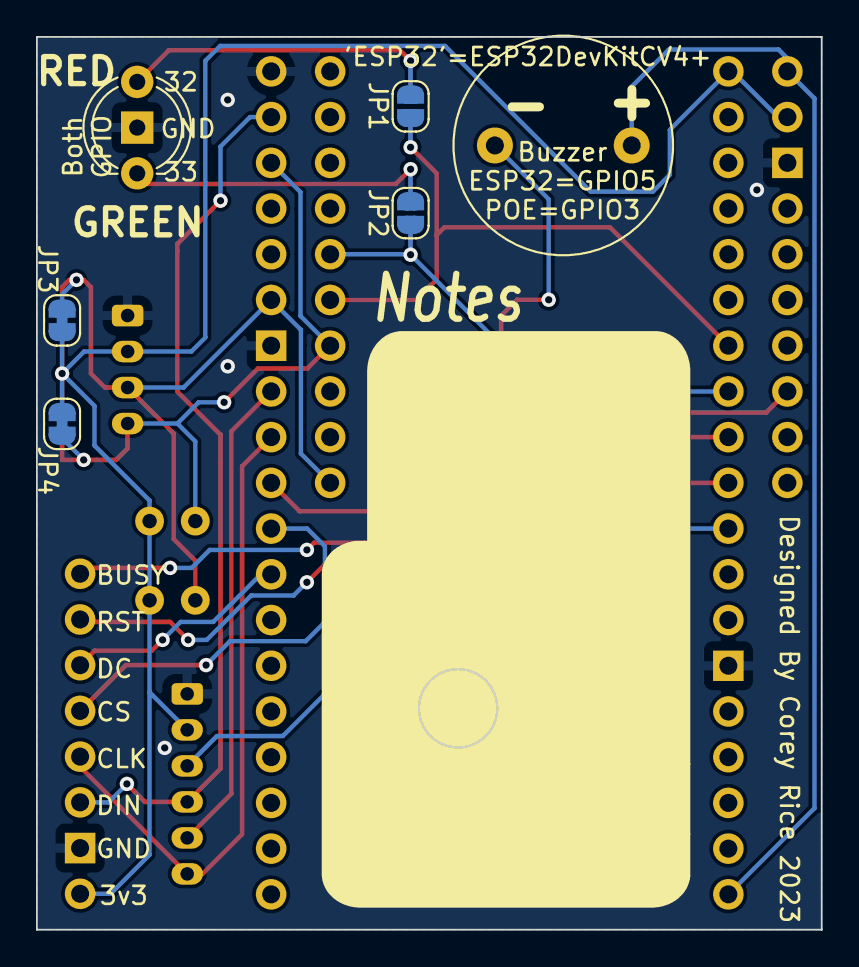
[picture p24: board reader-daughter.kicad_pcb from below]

Board: 2 copper layers, 43.6 x 49.6 mm, 22 parts (6 on the bottom side), 20 nets.

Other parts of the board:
J3: Conn_01x03_Male; LED_D5.0mm-3

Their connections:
GND: J3.2; also elsewhere on the board

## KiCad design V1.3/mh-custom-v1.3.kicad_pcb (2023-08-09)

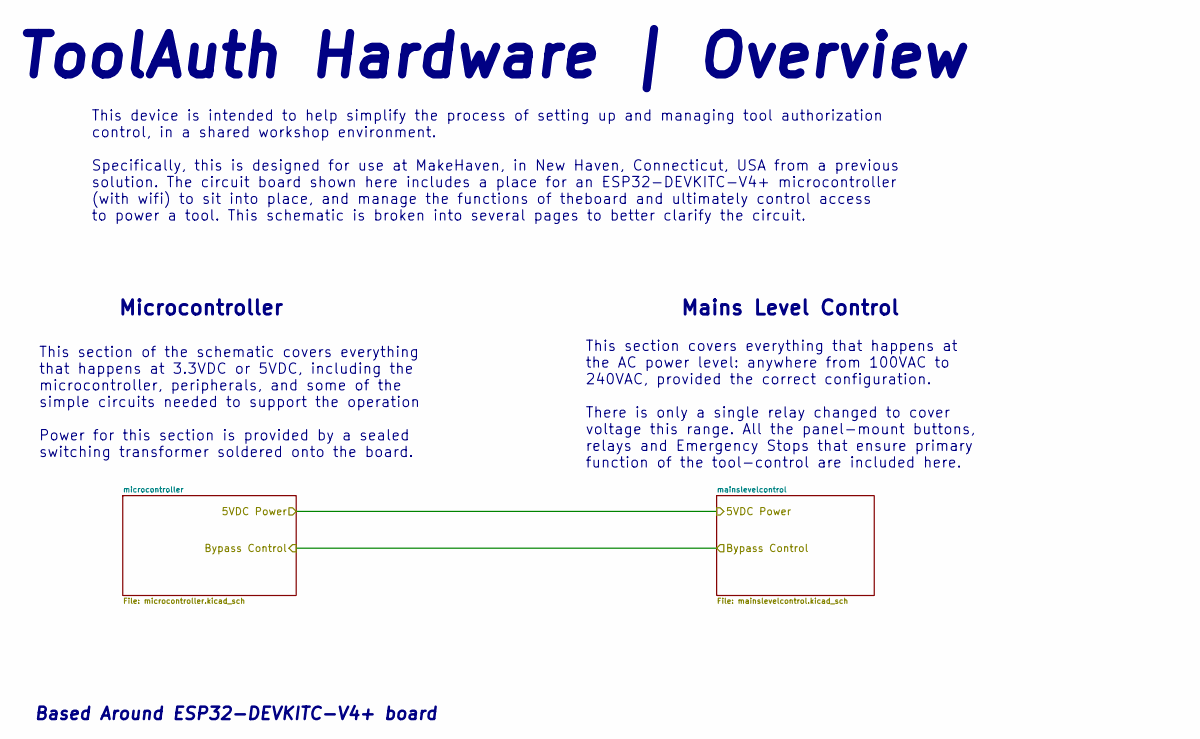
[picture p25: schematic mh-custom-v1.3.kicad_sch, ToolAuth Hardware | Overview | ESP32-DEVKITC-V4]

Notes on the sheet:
ToolAuth Hardware | Overview
Mains Level Control
Microcontroller
This section of the schematic covers everything that happens at 3.3VDC or 5VDC, including the microcontroller, peripherals, and some of the simple circuits needed to support the operation Power for this section is provided by a sealed switching transformer soldered onto the board.
This device is intended to help simplify the process of setting up and managing tool authorization control, in a shared workshop environment. Specifically, this is designed for use at MakeHaven, in New Haven, Connecticut, USA from a previous solution. The circuit board shown here includes a place f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
This section covers everything that happens at the AC power level: anywhere from 100VAC to 240VAC, provided the correct configuration. There is only a single relay changed to cover voltage this range. All the panel-mount buttons, relays and Emergency Stops that ensure primary function of the tool-c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
Based Around ESP32-DEVKITC-V4+ board

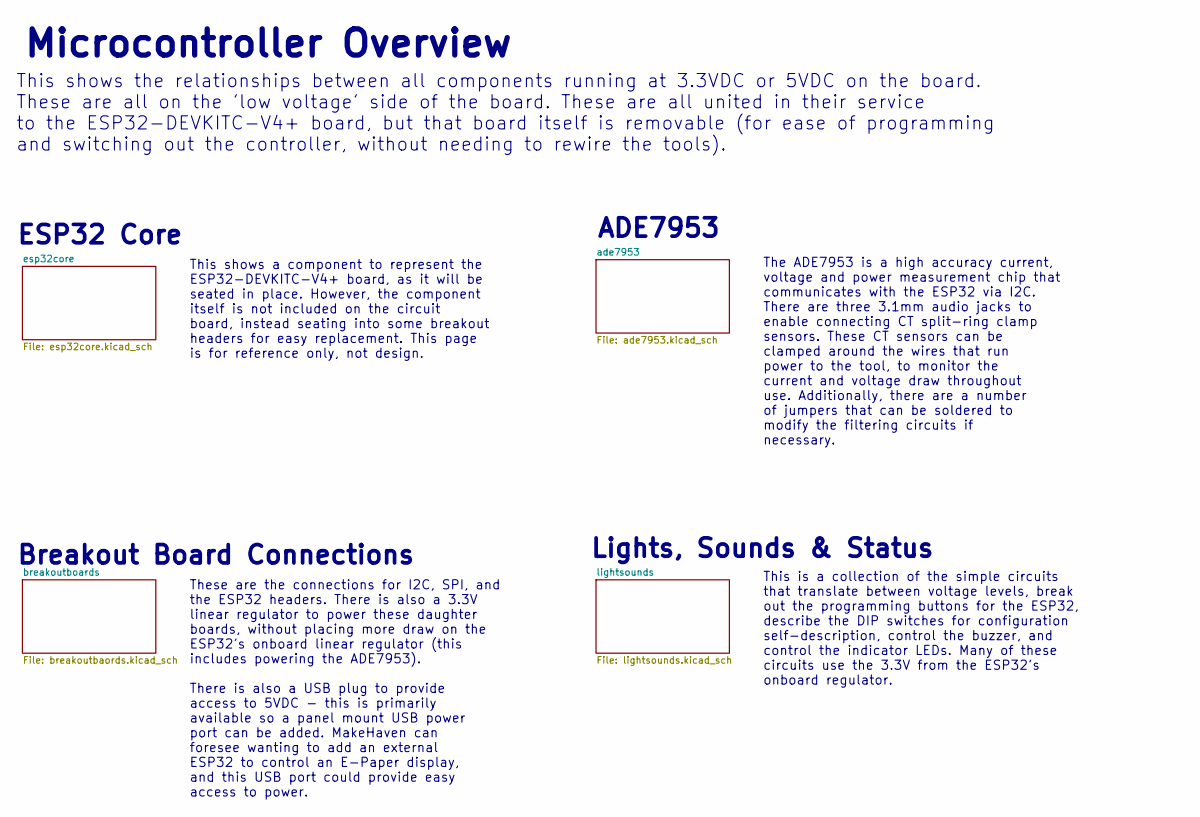
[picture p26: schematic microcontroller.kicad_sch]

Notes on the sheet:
This shows the relationships between all components running at 3.3VDC or 5VDC on the board. These are all on the 'low voltage' side of the board. These are all united in their service to the ESP32-DEVKITC-V4+ board, but that board itself is removable (for ease of programming and switching out the c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
This is a collection of the simple circuits that translate between voltage levels, break out the programming buttons for the ESP32, describe the DIP switches for configuration self-description, control the buzzer, and control the indicator LEDs. Many of these circuits use the 3.3V from the ESP32's 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
This shows a component to represent the ESP32-DEVKITC-V4+ board, as it will be seated in place. However, the component itself is not included on the circuit board, instead seating into some breakout headers for easy replacement. This page is for reference only, not design.
Breakout Board Connections
These are the connections for I2C, SPI, and the ESP32 headers. There is also a 3.3V linear regulator to power these daughter boards, without placing more draw on the ESP32's onboard linear regulator (this includes powering the ADE7953). There is also a USB plug to provide access to 5VDC - this is p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
Lights, Sounds & Status
The ADE7953 is a high accuracy current, voltage and power measurement chip that communicates with the ESP32 via I2C. There are three 3.1mm audio jacks to enable connecting CT split-ring clamp sensors. These CT sensors can be clamped around the wires that run power to the tool, to monitor the curren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
ESP32 Core
Microcontroller Overview
ADE7953

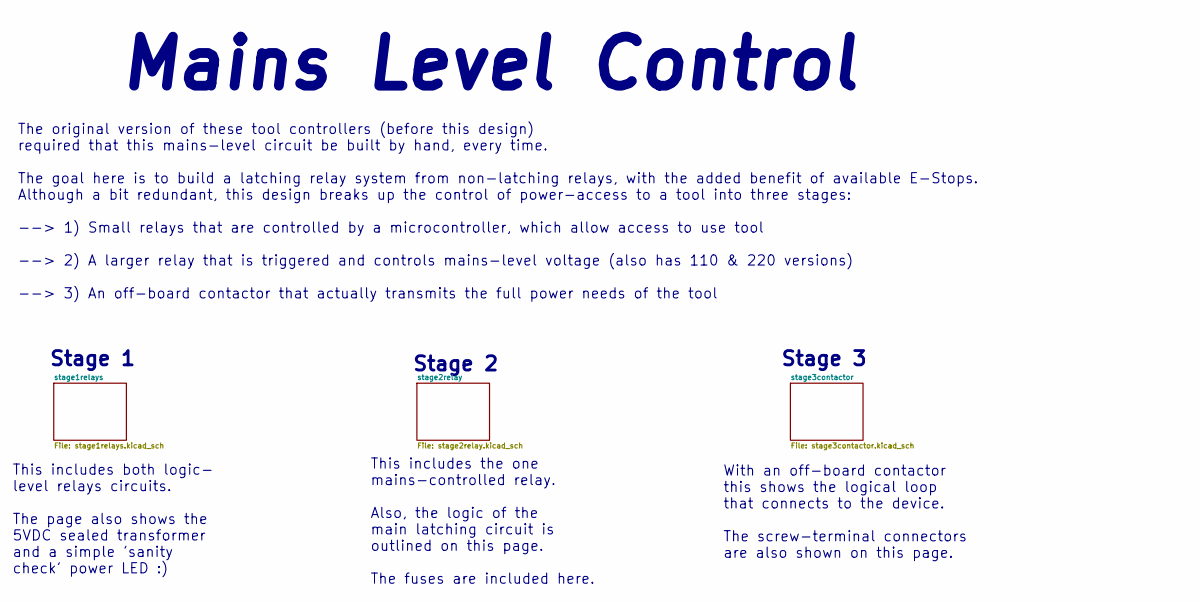
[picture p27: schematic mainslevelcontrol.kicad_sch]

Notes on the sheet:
With an off-board contactor this shows the logical loop that connects to the device. The screw-terminal connectors are also shown on this page.
This includes the one mains-controlled relay. Also, the logic of the main latching circuit is outlined on this page. The fuses are included here.
Stage 3
Mains Level Control
Stage 2
The original version of these tool controllers (before this design) required that this mains-level circuit be built by hand, every time. The goal here is to build a latching relay system from non-latching relays, with the added benefit of available E-Stops. Although a bit redundant, this design bre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
This includes both logic- level relays circuits. The page also shows the 5VDC sealed transformer and a simple 'sanity check' power LED :)
Stage 1

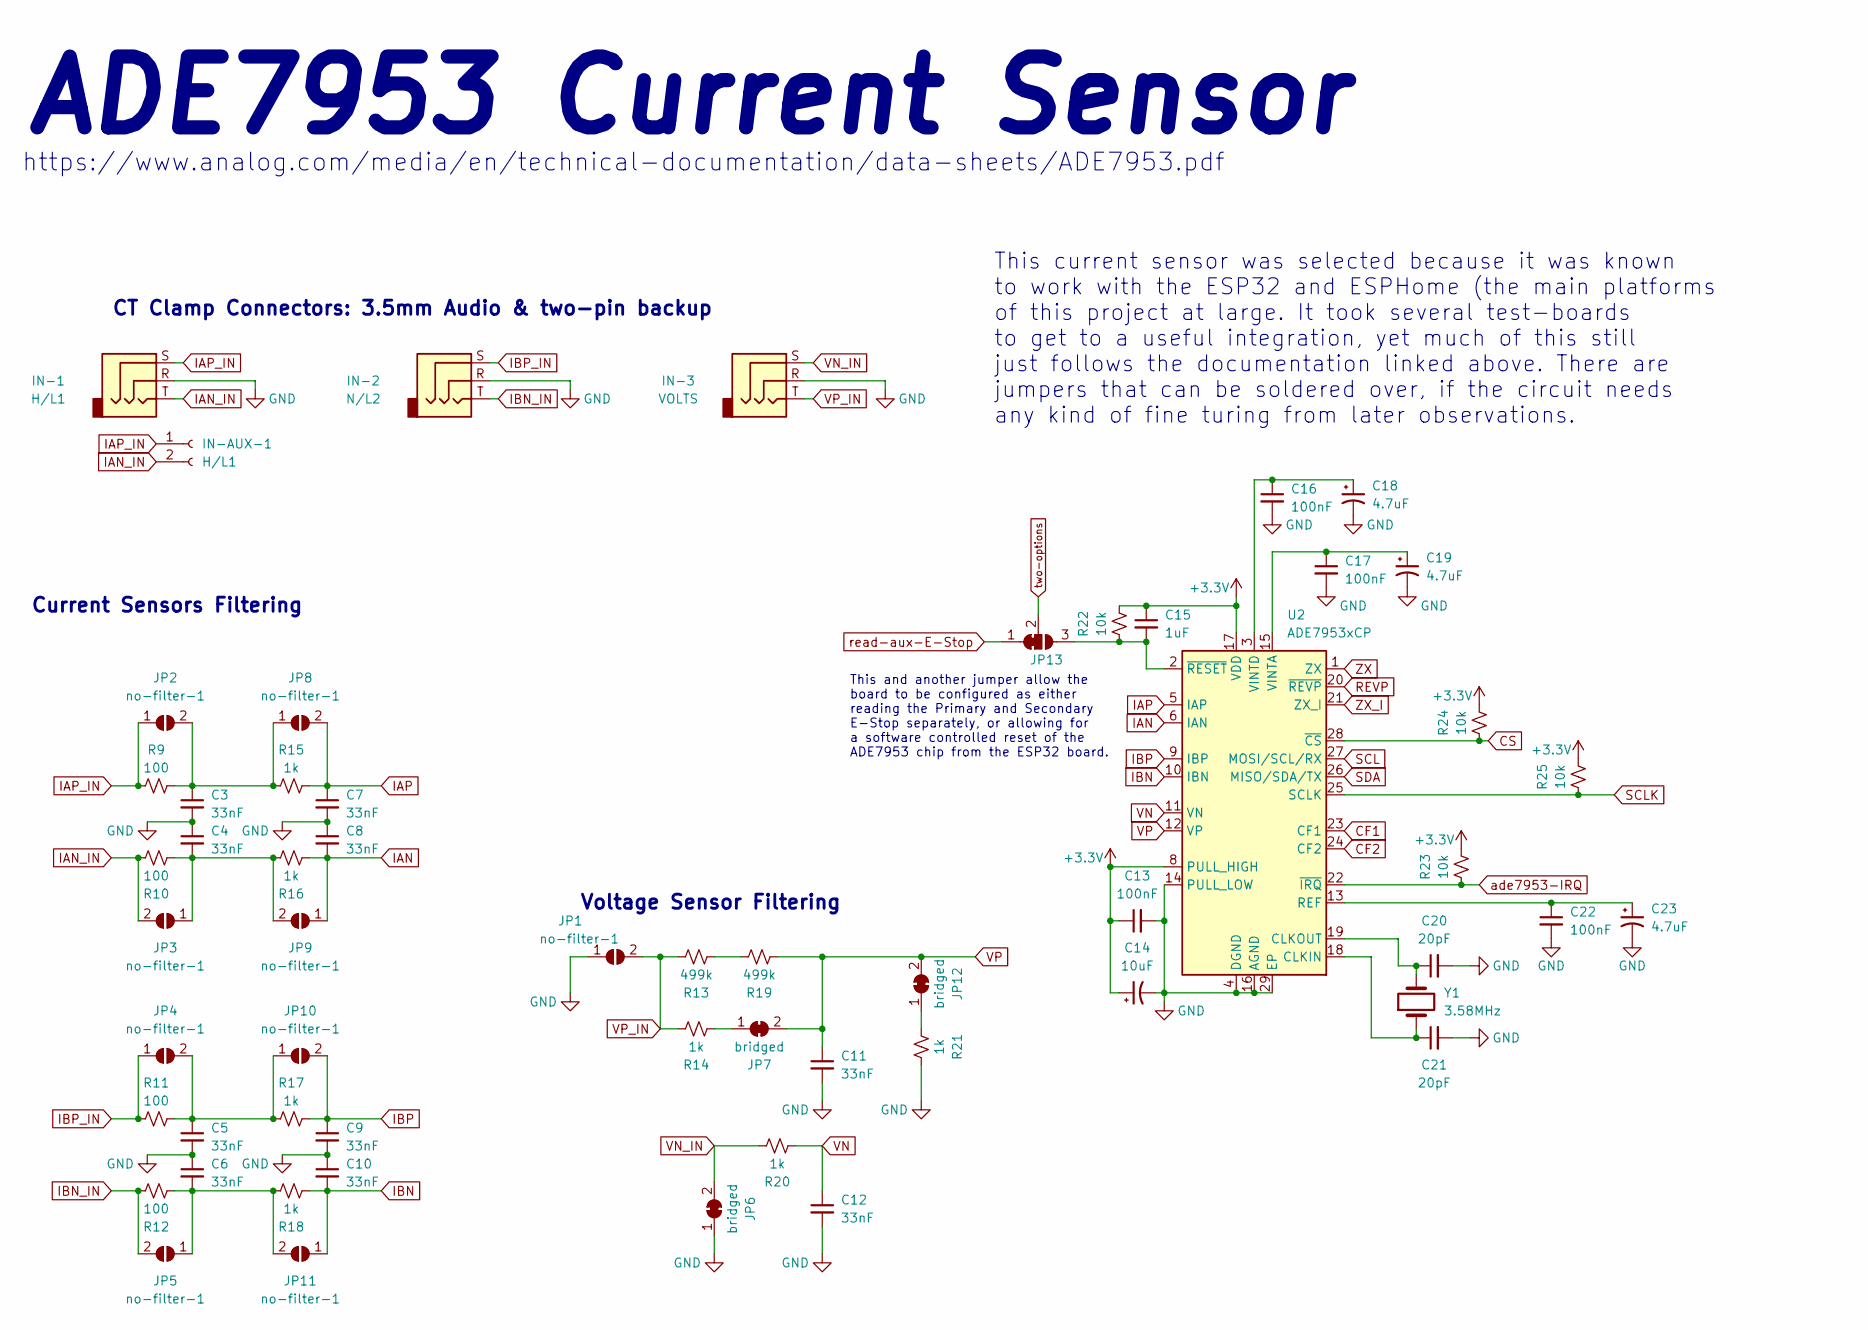
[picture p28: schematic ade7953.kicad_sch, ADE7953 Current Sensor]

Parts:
C3, C4, C5, C6, C7, C8, C9, C10, C11, C12: 33nF; LED_0603_1608Metric; JLCPCB Part # C21117
C13, C16, C17, C22: 100nF; LED_0603_1608Metric; JLCPCB Part # C14663
C14: 10uF; CP_Radial_D5.0mm_P2.00mm; JLCPCB Part # C88726
C15: 1uF; LED_0603_1608Metric; JLCPCB Part # C15849
C18, C19, C23: 4.7uF; CP_Radial_D5.0mm_P2.00mm; JLCPCB Part # C88759
C20, C21: 20pF; LED_0603_1608Metric; JLCPCB Part # C1648
IN-1: H/L1; Jack_3.5mm_CUI_SJ1-3525N_Horizontal; JLCPCB Part # C692542
IN-2: N/L2; Jack_3.5mm_CUI_SJ1-3525N_Horizontal; JLCPCB Part # C692542
IN-3: VOLTS; Jack_3.5mm_CUI_SJ1-3525N_Horizontal; JLCPCB Part # C692542
IN-AUX-1: H/L1; PinHeader_1x02_P2.54mm_Vertical
JP1, JP2, JP3, JP4, JP5, JP8, JP9, JP10, JP11: no-filter-1; SolderJumper-2_P1.3mm_Open_RoundedPad1.0x1.5mm
JP6, JP7, JP12: bridged; SolderJumper-2_P1.3mm_Bridged_RoundedPad1.0x1.5mm
JP13: SolderJumper_3_Bridged12; SolderJumper-3_P1.3mm_Bridged12_RoundedPad1.0x1.5mm
R9, R10, R11, R12: 100; R_0603_1608Metric; JLCPCB Part # C22775
R13, R19: 499k; R_0603_1608Metric; JLCPCB Part # C131054
R14, R15, R16, R17, R18, R20, R21: 1k; R_0603_1608Metric; JLCPCB Part # C21190
R22, R23, R24, R25: 10k; R_0603_1608Metric; JLCPCB Part # C25804
U2: ADE7953xCP; LFCSP-28-1EP_5x5mm_P0.5mm_EP3.14x3.14mm; JLCPCB Part # C515890
Y1: 3.58MHz; Crystal_HC49-4H_Vertical; JLCPCB Part # C2826865

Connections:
+3.3V: C13.1, C14.1, C15.1, R22.2, R23.2, R24.2, R25.2, U2.7 (PULL_HIGH), U2.8 (PULL_HIGH), U2.17 (VDD); also elsewhere on the board
CF1: U2.23 (CF1)
CF2: U2.24 (CF2)
CS: R24.1, U2.28 (~CS)
GND: C3.2, C4.1, C5.2, C6.1, C7.2, C8.1, C9.2, C10.1, C11.2, C12.2, C13.2, C14.2, C16.2, C17.2, C18.2, C19.2, C20.2, C21.2, C22.2, C23.2, IN-1.R, IN-2.R, IN-3.R, JP1.1 (A), JP6.1 (A), R21.2, U2.4 (DGND), U2.14 (PULL_LOW), U2.16 (AGND), U2.29 (EP); also elsewhere on the board
IAN: C8.2, JP9.1 (A), R16.1, U2.6 (IAN)
IAN_IN: IN-1.T, IN-AUX-1.2, JP3.2 (B), R10.2
IAP: C7.1, JP8.2 (B), R15.2, U2.5 (IAP)
IAP_IN: IN-1.S, IN-AUX-1.1, JP2.1 (A), R9.1
IBN: C10.2, JP11.1 (A), R18.1, U2.10 (IBN)
IBN_IN: IN-2.T, JP5.2 (B), R12.2
IBP: C9.1, JP10.2 (B), R17.2, U2.9 (IBP)
IBP_IN: IN-2.S, JP4.1 (A), R11.1
unnamed: C3.1, JP2.2 (B), JP8.1 (A), R9.2, R15.1
unnamed: C4.2, JP3.1 (A), JP9.2 (B), R10.1, R16.2
unnamed: C5.1, JP4.2 (B), JP10.1 (A), R11.2, R17.1
unnamed: C6.2, JP5.1 (A), JP11.2 (B), R12.1, R18.2
unnamed: C15.2, JP13.3 (B), R22.1, U2.2 (~RESET)
unnamed: C16.1, C18.1, U2.3 (VINTD)
unnamed: C17.1, C19.1, U2.15 (VINTA)
unnamed: C20.1, U2.19 (CLKOUT), Y1.2
unnamed: C21.1, U2.18 (CLKIN), Y1.1
unnamed: C22.1, C23.1, U2.13 (REF)
unnamed: JP7.1 (A), R14.1
unnamed: JP12.1 (A), R21.1
unnamed: R13.1, R19.2
REVP: U2.20 (~REVP)
SCL: U2.27 (MOSI/SCL/RX); also elsewhere on the board
SCLK: R25.1, U2.25 (SCLK)
SDA: U2.26 (MISO/SDA/TX); also elsewhere on the board
VN: C12.1, R20.1, U2.11 (VN)
VN_IN: IN-3.S, JP6.2 (B), R20.2
VP: C11.1, JP7.2 (B), JP12.2 (B), R19.1, U2.12 (VP)
VP_IN: IN-3.T, JP1.2 (B), R13.2, R14.2
ZX: U2.1 (ZX)
ZX_I: U2.21 (ZX_I)
ade7953-IRQ: R23.1, U2.22 (~IRQ); also elsewhere on the board
read-aux-E-Stop: JP13.1 (A); also elsewhere on the board
two-options: JP13.2 (C); also elsewhere on the board

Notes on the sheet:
CT Clamp Connectors: 3.5mm Audio & two-pin backup
Voltage Sensor Filtering
https://www.analog.com/media/en/technical-documentation/data-sheets/ADE7953.pdf
ADE7953 Current Sensor
This current sensor was selected because it was known to work with the ESP32 and ESPHome (the main platforms of this project at large. It took several test-boards to get to a useful integration, yet much of this still just follows the documentation linked above. There are jumpers that can be solder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
Current Sensors Filtering
This and another jumper allow the board to be configured as either reading the Primary and Secondary E-Stop separately, or allowing for a software controlled reset of the ADE7953 chip from the ESP32 board.

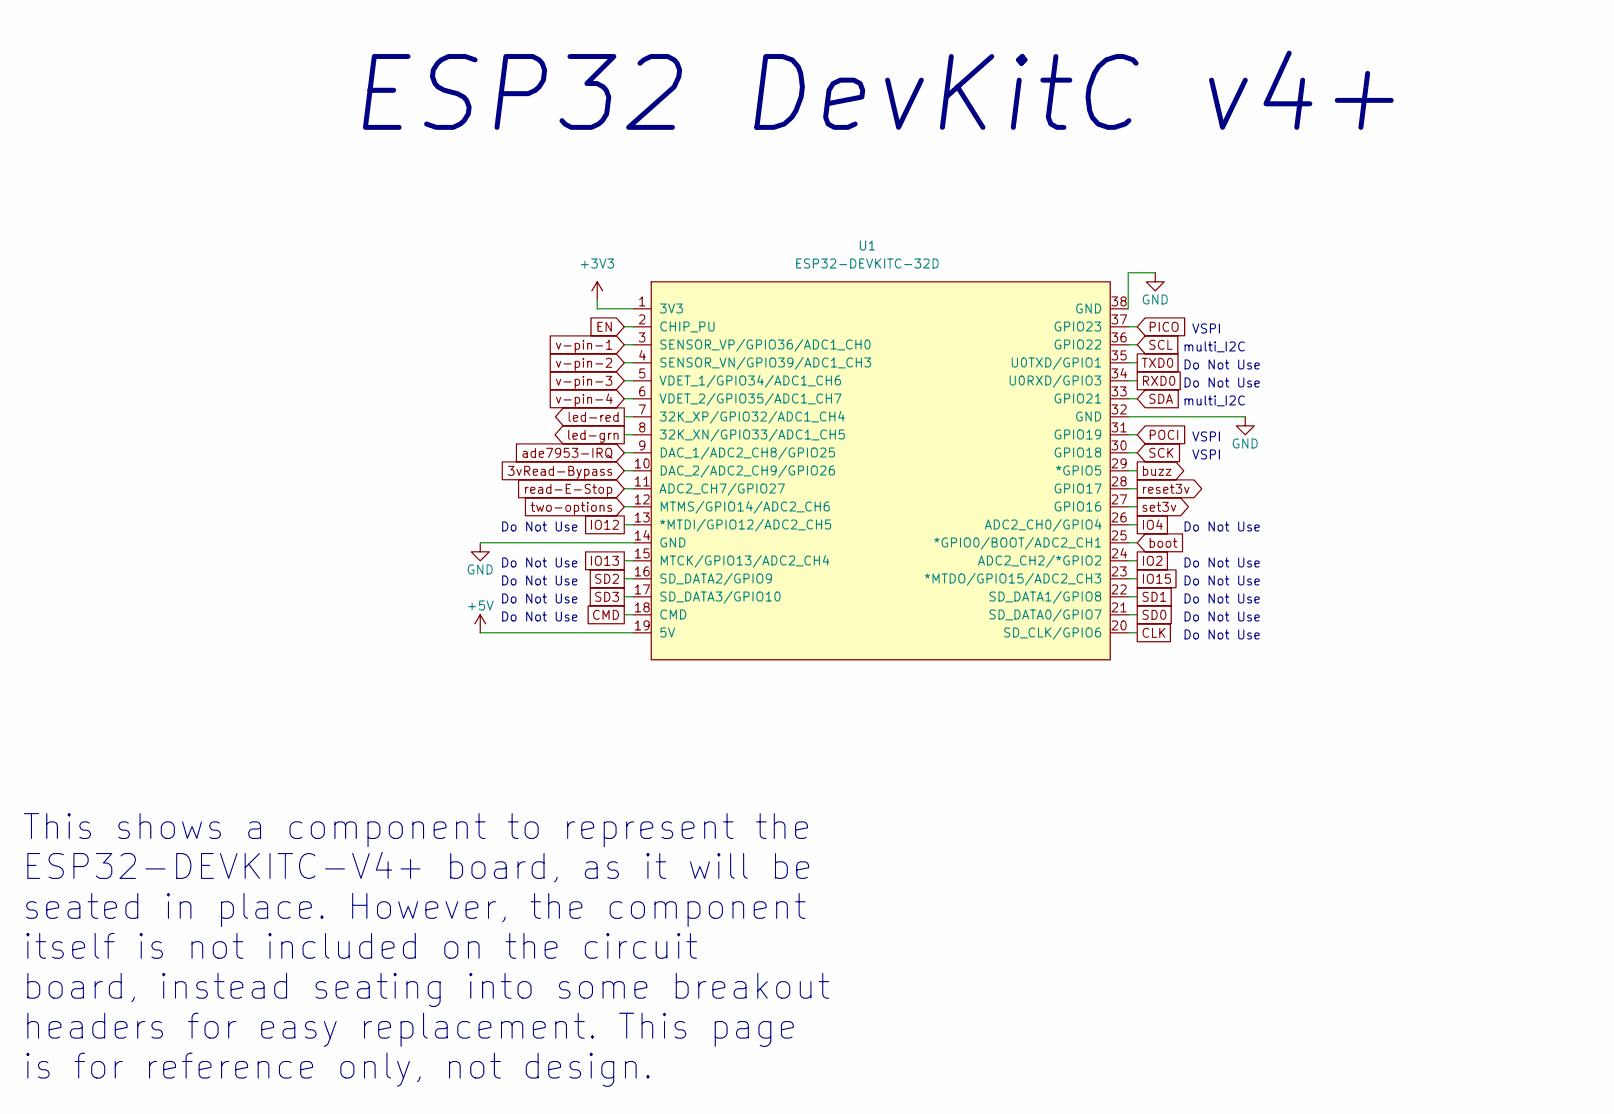
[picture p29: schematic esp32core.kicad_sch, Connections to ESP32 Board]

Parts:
U1: ESP32-DEVKITC-32D; ESP32-DevKitC; PARTREV 4

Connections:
unnamed: U1.14 (GND), U1.32 (GND), U1.38 (GND)

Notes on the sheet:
Do Not Use
ESP32 DevKitC v4+
VSPI
multi_I2C
This shows a component to represent the ESP32-DEVKITC-V4+ board, as it will be seated in place. However, the component itself is not included on the circuit board, instead seating into some breakout headers for easy replacement. This page is for reference only, not design.

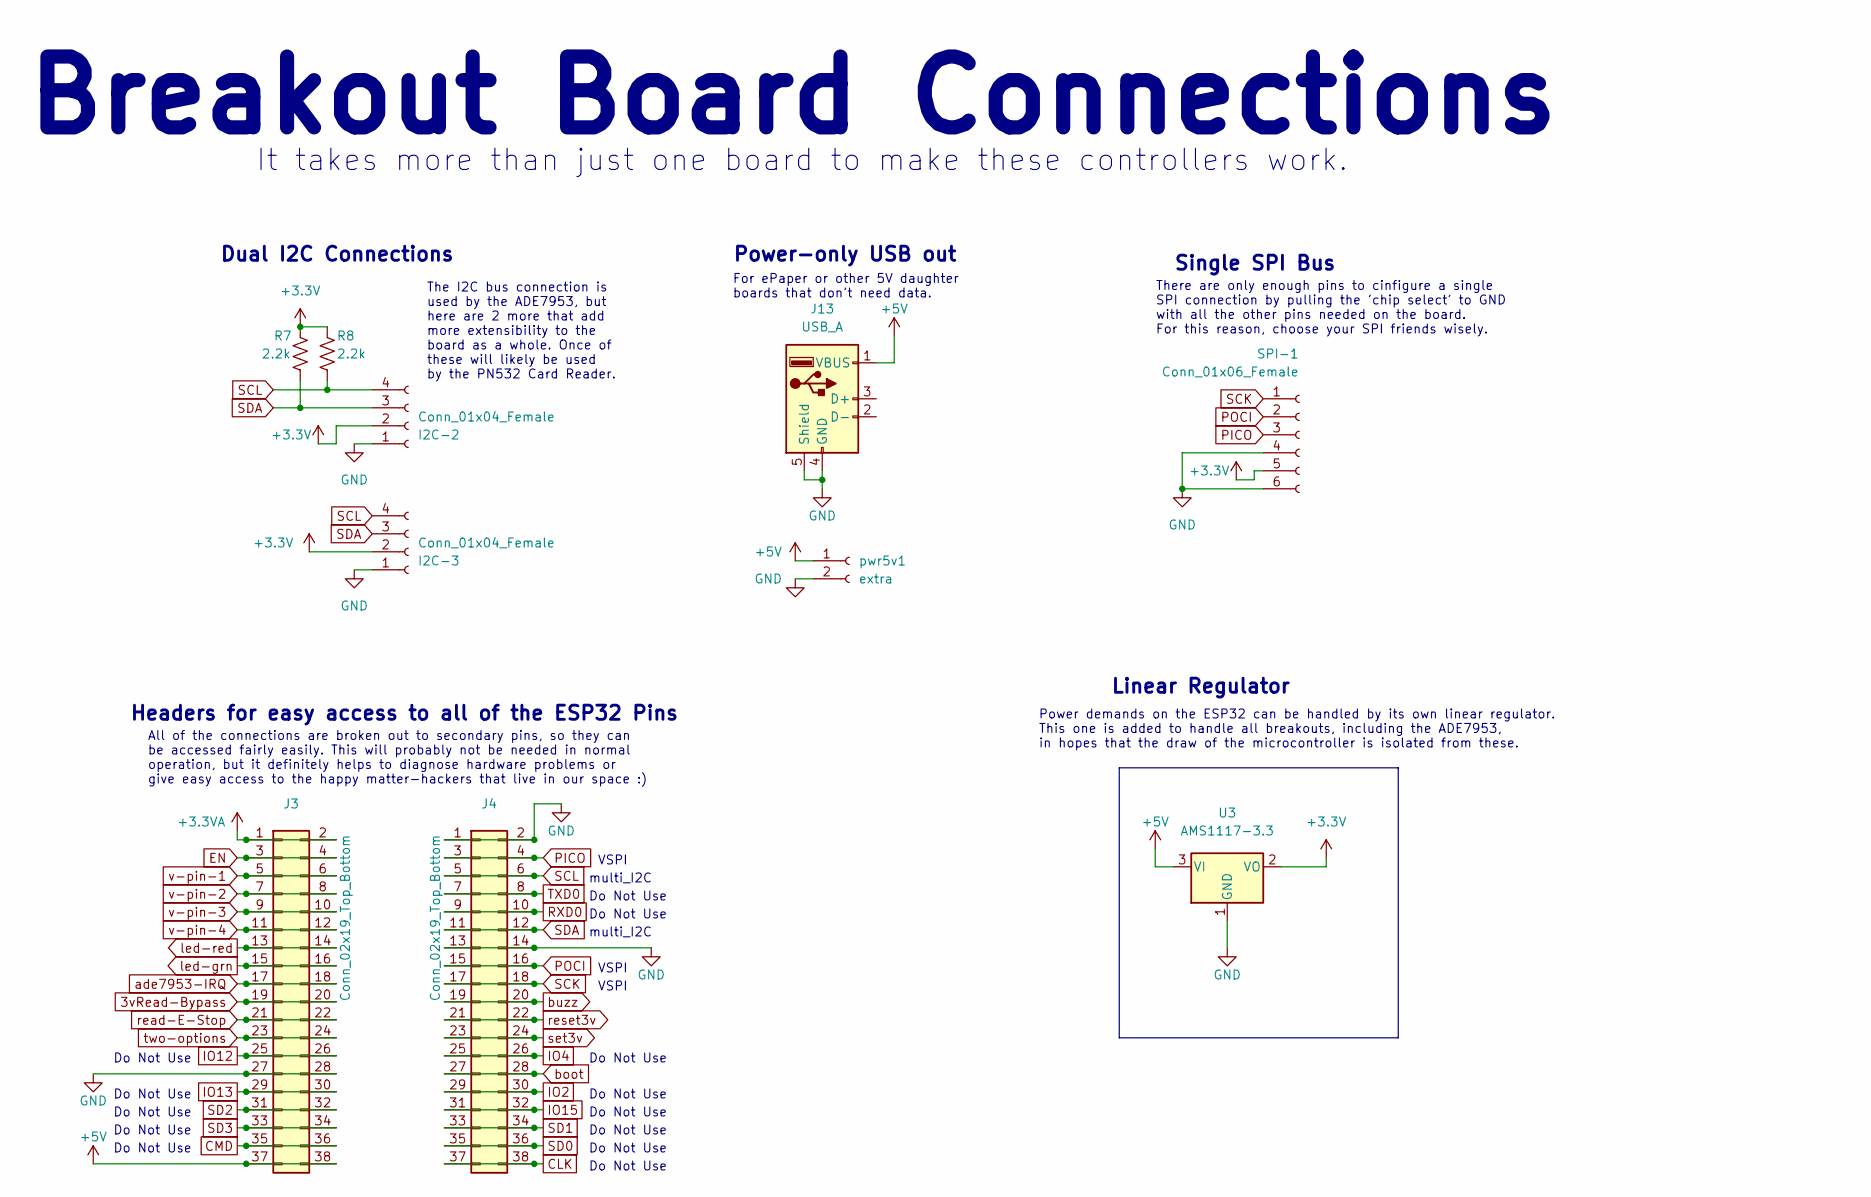
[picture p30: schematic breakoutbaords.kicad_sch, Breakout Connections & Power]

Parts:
I2C-2, I2C-3: Conn_01x04_Female; JST_PH_B4B-PH-K_1x04_P2.00mm_Vertical; JLCPCB Part # C131334
J3, J4: Conn_02x19_Top_Bottom; PinSocket_2x19_P2.54mm_Vertical; JLCPCB Part # C2897420
J13: USB_A; USB-A-TH_UBAS-4R-D14D-4D-LF-SN; JLCPCB Part # C265461
R7, R8: 2.2k; R_0603_1608Metric; JLCPCB Part # C4190
SPI-1: Conn_01x06_Female; JST_PH_B6B-PH-K_1x06_P2.00mm_Vertical; JLCPCB Part # C131342
U3: AMS1117-3.3; SOT-223-3_TabPin2; JLCPCB Part # C6186
pwr5v1: extra; PinHeader_1x02_P2.54mm_Vertical

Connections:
3vRead-Bypass: J3.19, J3.20; also elsewhere on the board
+3.3V: I2C-2.2, I2C-3.2, R7.2, R8.2, SPI-1.5, U3.2 (VO); also elsewhere on the board
+3.3VA: J3.1, J3.2; also elsewhere on the board
+5V: J3.37, J3.38, J13.1 (VBUS), U3.3 (VI), pwr5v1.1; also elsewhere on the board
CLK: J4.37, J4.38
CMD: J3.35, J3.36
EN: J3.3, J3.4; also elsewhere on the board
GND: I2C-2.1, I2C-3.1, J3.27, J3.28, J4.1, J4.2, J4.13, J4.14, J13.4 (GND), J13.5 (Shield), SPI-1.4, SPI-1.6, U3.1 (GND), pwr5v1.2; also elsewhere on the board
IO2: J4.29, J4.30
IO4: J4.25, J4.26
IO12: J3.25, J3.26
IO13: J3.29, J3.30
IO15: J4.31, J4.32
PICO: J4.3, J4.4, SPI-1.3
POCI: J4.15, J4.16, SPI-1.2
RXD0: J4.9, J4.10
SCK: J4.17, J4.18, SPI-1.1
SCL: I2C-2.4, I2C-3.4, J4.5, J4.6, R8.1; also elsewhere on the board
SD0: J4.35, J4.36
SD1: J4.33, J4.34
SD2: J3.31, J3.32
SD3: J3.33, J3.34
SDA: I2C-2.3, I2C-3.3, J4.11, J4.12, R7.1; also elsewhere on the board
TXD0: J4.7, J4.8
ade7953-IRQ: J3.17, J3.18; also elsewhere on the board
boot: J4.27, J4.28; also elsewhere on the board
buzz: J4.19, J4.20; also elsewhere on the board
led-grn: J3.15, J3.16; also elsewhere on the board
led-red: J3.13, J3.14; also elsewhere on the board
read-E-Stop: J3.21, J3.22; also elsewhere on the board
reset3v: J4.21, J4.22; also elsewhere on the board
set3v: J4.23, J4.24; also elsewhere on the board
two-options: J3.23, J3.24; also elsewhere on the board
v-pin-1: J3.5, J3.6; also elsewhere on the board
v-pin-2: J3.7, J3.8; also elsewhere on the board
v-pin-3: J3.9, J3.10; also elsewhere on the board
v-pin-4: J3.11, J3.12; also elsewhere on the board

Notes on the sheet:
VSPI
Single SPI Bus
Do Not Use
All of the connections are broken out to secondary pins, so they can be accessed fairly easily. This will probably not be needed in normal operation, but it definitely helps to diagnose hardware problems or give easy access to the happy matter-hackers that live in our space :)
For ePaper or other 5V daughter boards that don't need data.
Power demands on the ESP32 can be handled by its own linear regulator. This one is added to handle all breakouts, including the ADE7953, in hopes that the draw of the microcontroller is isolated from these.
multi_I2C
Dual I2C Connections
Linear Regulator
Breakout Board Connections
The I2C bus connection is used by the ADE7953, but here are 2 more that add more extensibility to the board as a whole. Once of these will likely be used by the PN532 Card Reader.
It takes more than just one board to make these controllers work.
Power-only USB out
There are only enough pins to cinfigure a single SPI connection by pulling the 'chip select' to GND with all the other pins needed on the board. For this reason, choose your SPI friends wisely.
Headers for easy access to all of the ESP32 Pins

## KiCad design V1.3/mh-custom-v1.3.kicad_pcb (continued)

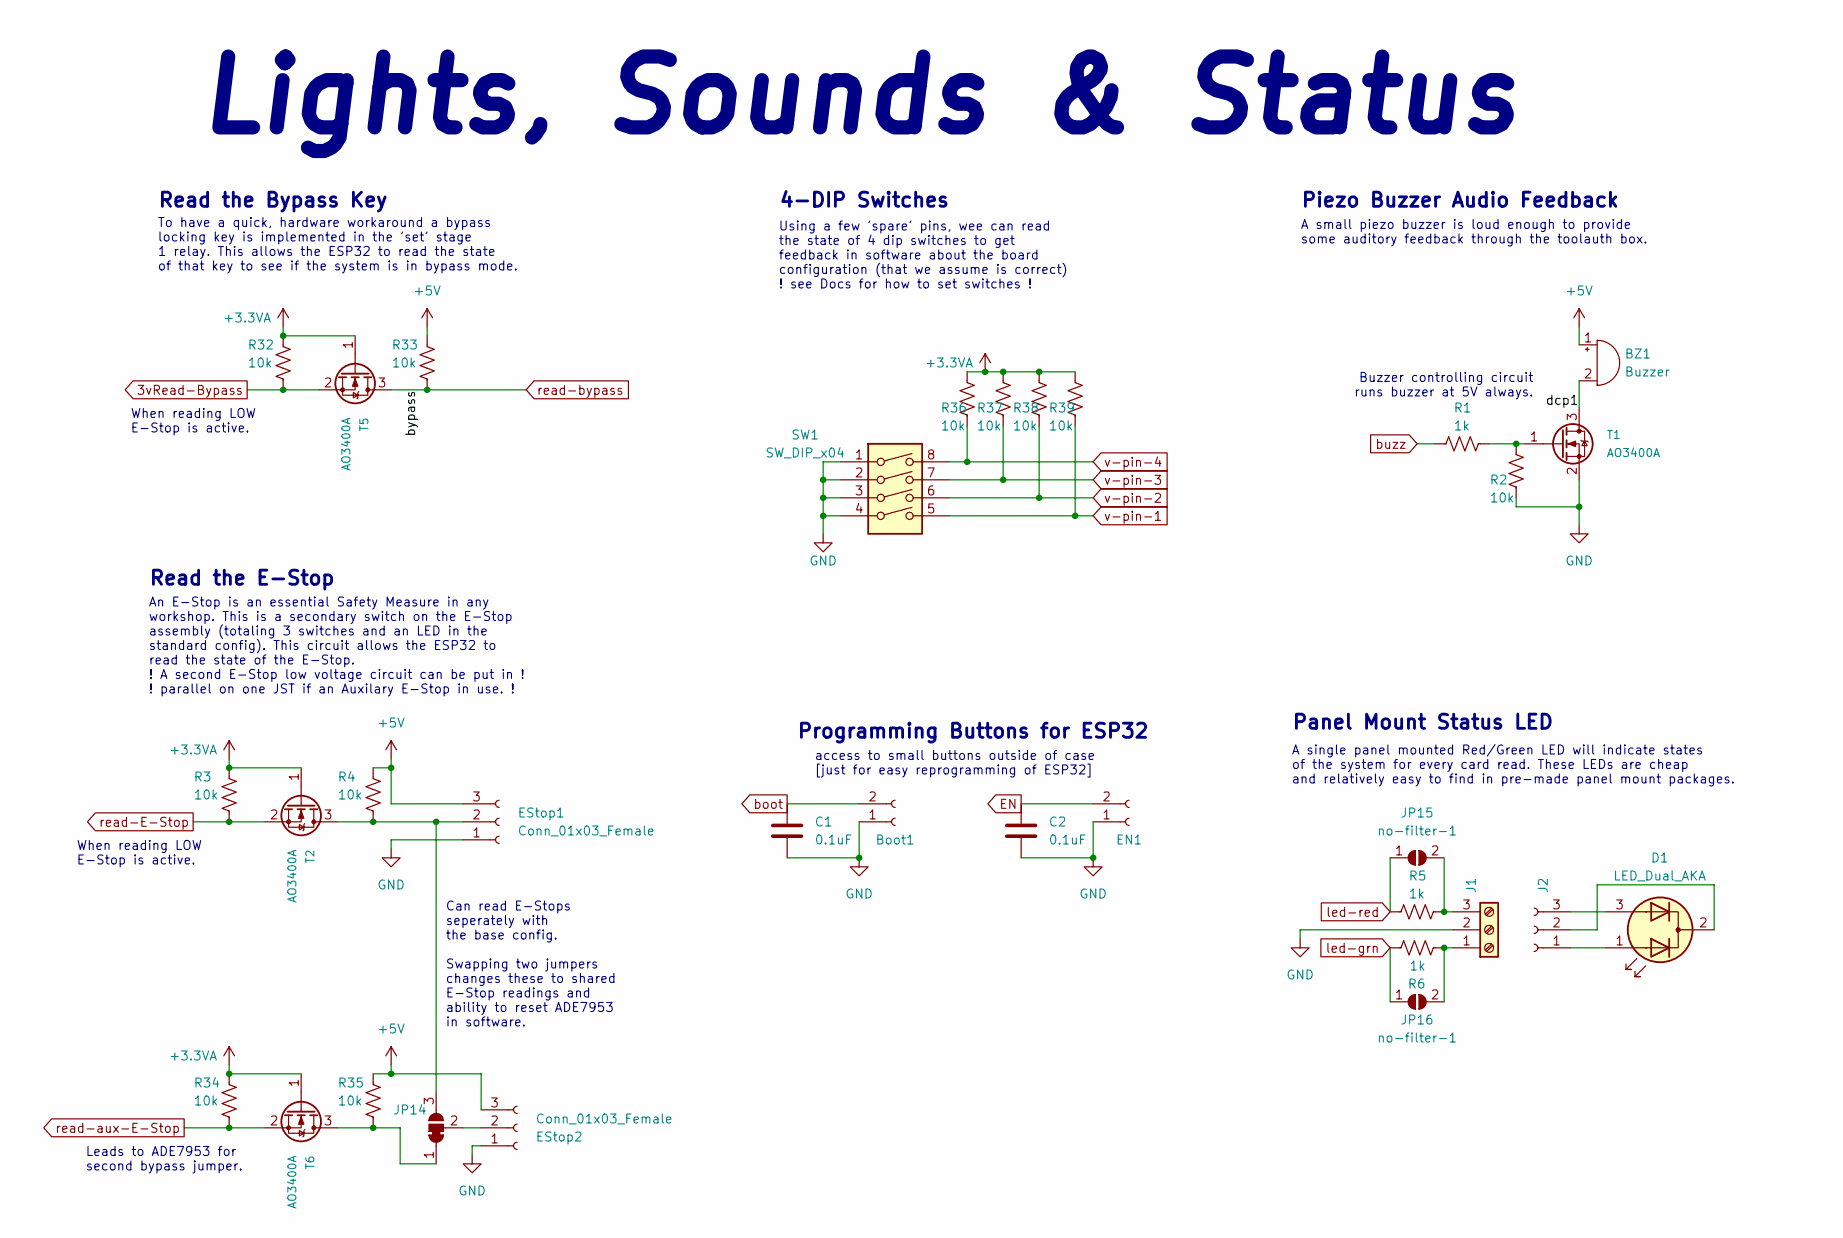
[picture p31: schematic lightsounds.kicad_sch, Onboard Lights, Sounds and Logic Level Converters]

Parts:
BZ1: Buzzer; Buzzer_12x9.5RM7.6; JLCPCB Part # C96095
Boot1: Conn_01x02_Female; PinSocket_1x02_P2.54mm_Vertical
C1, C2: 0.1uF; LED_0603_1608Metric; JLCPCB Part # C14663
D1: LED_Dual_AKA
EN1: Conn_01x02_Female; PinSocket_1x02_P2.54mm_Vertical
EStop1, EStop2: Conn_01x03_Female; JST_PH_B3B-PH-K_1x03_P2.00mm_Vertical; JLCPCB Part # C131339
J1: Conn_01x03_Male; TerminalBlock_TE_282834-3_1x03_P2.54mm_Horizontal; JLCPCB Part # C557686
J2: Conn_01x03_Female
JP14: SolderJumper_3_Bridged12; SolderJumper-3_P1.3mm_Bridged12_RoundedPad1.0x1.5mm
JP15, JP16: no-filter-1; SolderJumper-2_P1.3mm_Open_RoundedPad1.0x1.5mm
R1, R5, R6: 1k; R_0603_1608Metric; JLCPCB Part # C21190
R2, R3, R4, R32, R33, R34, R35, R36, R37, R38, R39: 10k; R_0603_1608Metric; JLCPCB Part # C25804
SW1: SW_DIP_x04; SW_DIP_SPSTx04_Slide_Omron_A6H-4101_W6.15mm_P1.27mm; JLCPCB Part # C224996
T1, T2, T5, T6: AO3400A; SOT-23; JLCPCB Part # C427382

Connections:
3vRead-Bypass: R32.1, T5.2 (S); also elsewhere on the board
+3.3VA: R3.2, R32.2, R34.2, R36.2, R37.2, R38.2, R39.2, T2.1 (G), T5.1 (G), T6.1 (G); also elsewhere on the board
+5V: BZ1.1 (-), EStop1.3, EStop2.3, R4.2, R33.2, R35.2; also elsewhere on the board
/microcontroller/lightsounds/dcp1: BZ1.2 (+), T1.3 (D)
EN: C2.1, EN1.2; also elsewhere on the board
GND: Boot1.1, C1.2, C2.2, EN1.1, EStop1.1, EStop2.1, J1.2, R2.1, SW1.1, SW1.2, SW1.3, SW1.4, T1.2 (S); also elsewhere on the board
unnamed: D1.1 (A1), J2.1
unnamed: D1.2 (K), J2.2
unnamed: D1.3 (A2), J2.3
unnamed: EStop1.2, JP14.3 (B), R4.1, T2.3 (D)
unnamed: EStop2.2, JP14.2 (C)
unnamed: J1.1, JP16.2 (B), R6.1
unnamed: J1.3, JP15.2 (B), R5.2
unnamed: JP14.1 (A), R35.1, T6.3 (D)
unnamed: R1.2, R2.2, T1.1 (G)
boot: Boot1.2, C1.1; also elsewhere on the board
buzz: R1.1; also elsewhere on the board
led-grn: JP16.1 (A), R6.2; also elsewhere on the board
led-red: JP15.1 (A), R5.1; also elsewhere on the board
read-E-Stop: R3.1, T2.2 (S); also elsewhere on the board
read-aux-E-Stop: R34.1, T6.2 (S); also elsewhere on the board
read-bypass: R33.1, T5.3 (D); also elsewhere on the board
v-pin-1: R39.1, SW1.5; also elsewhere on the board
v-pin-2: R38.1, SW1.6; also elsewhere on the board
v-pin-3: R37.1, SW1.7; also elsewhere on the board
v-pin-4: R36.1, SW1.8; also elsewhere on the board

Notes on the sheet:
Programming Buttons for ESP32
Leads to ADE7953 for second bypass jumper.
4-DIP Switches
A single panel mounted Red/Green LED will indicate states of the system for every card read. These LEDs are cheap and relatively easy to find in pre-made panel mount packages.
Can read E-Stops seperately with the base config. Swapping two jumpers changes these to shared E-Stop readings and ability to reset ADE7953 in software.
A small piezo buzzer is loud enough to provide some auditory feedback through the toolauth box.
access to small buttons outside of case [just for easy reprogramming of ESP32]
Read the E-Stop
When reading LOW E-Stop is active.
An E-Stop is an essential Safety Measure in any workshop. This is a secondary switch on the E-Stop assembly (totaling 3 switches and an LED in the standard config). This circuit allows the ESP32 to read the state of the E-Stop. ! A second E-Stop low voltage circuit can be put in ! ! parallel on one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
Buzzer controlling circuit runs buzzer at 5V always.
To have a quick, hardware workaround a bypass locking key is implemented in the 'set' stage 1 relay. This allows the ESP32 to read the state of that key to see if the system is in bypass mode.
Piezo Buzzer Audio Feedback
Panel Mount Status LED
Lights, Sounds & Status
Using a few 'spare' pins, wee can read the state of 4 dip switches to get feedback in software about the board configuration (that we assume is correct) ! see Docs for how to set switches !
Read the Bypass Key

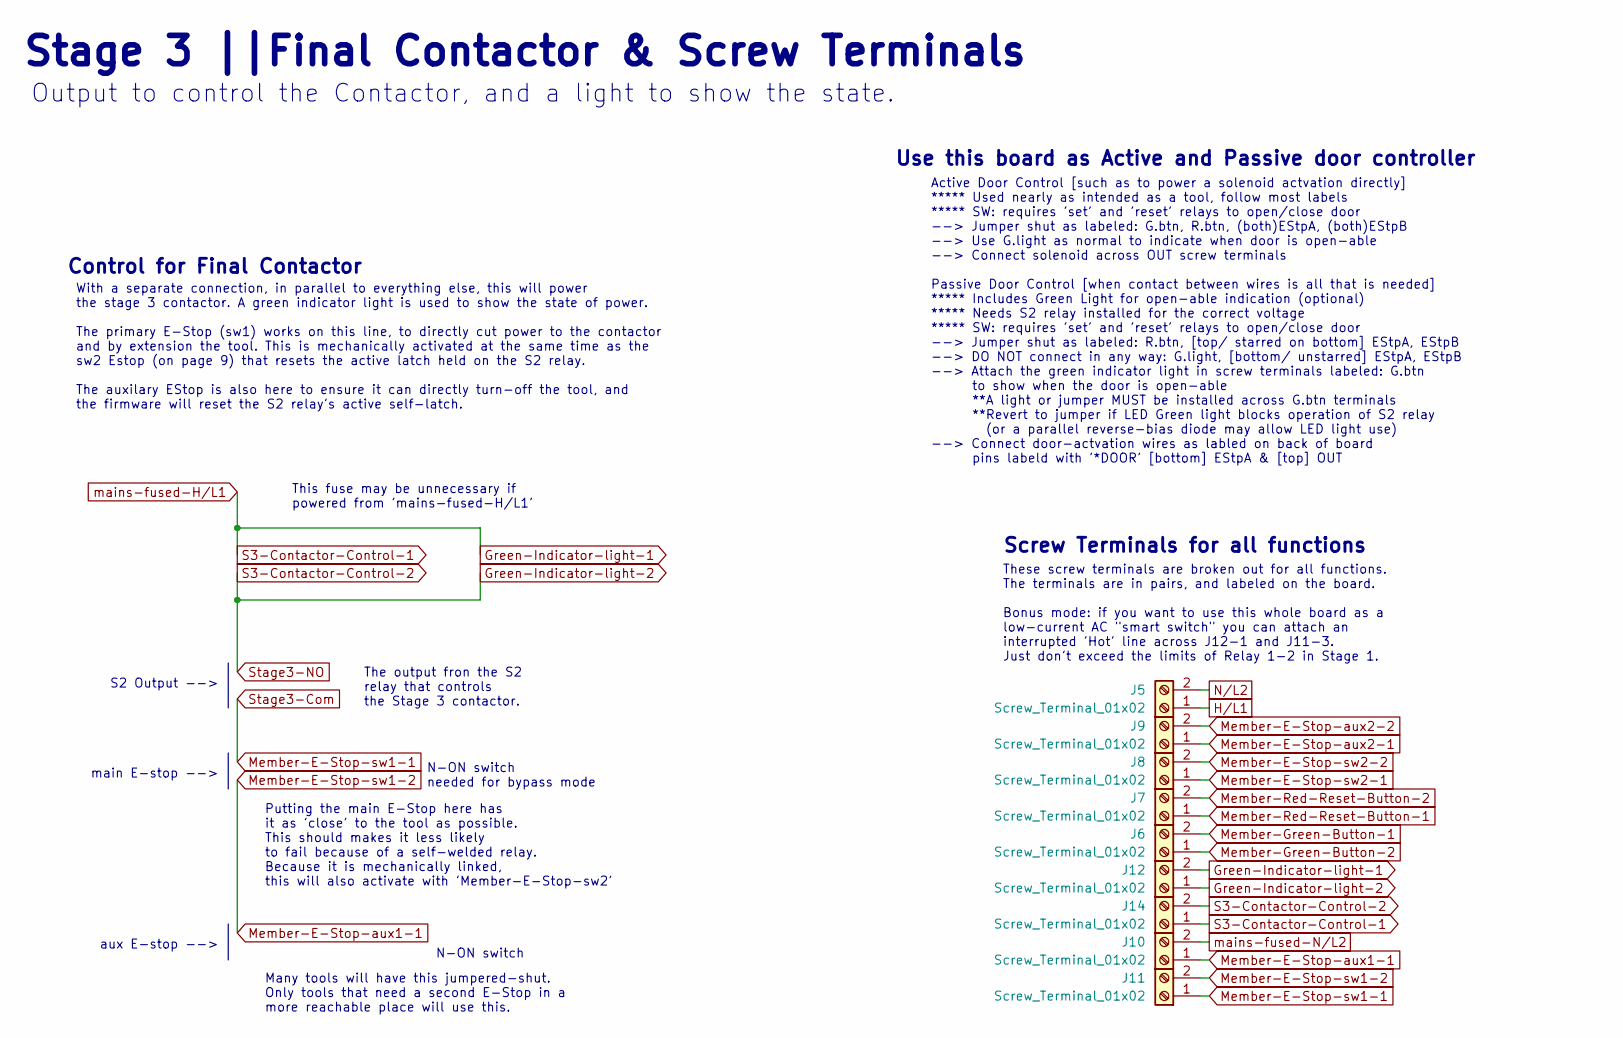
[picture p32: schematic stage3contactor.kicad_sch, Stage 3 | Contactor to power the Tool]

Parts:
J5, J6, J7, J8, J9, J10, J11, J12, J14: Screw_Terminal_01x02; TerminalBlock_Altech_AK300-2_P5.00mm; JLCPCB Part # C8269

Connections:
Green-Indicator-light-1: J12.2, J14.1; also elsewhere on the board
Green-Indicator-light-2: J12.1, J14.2; also elsewhere on the board
H/L1: J5.1; also elsewhere on the board
Member-E-Stop-aux1-1: J10.1, J11.2
Member-E-Stop-aux2-2: J9.2, J10.2; also elsewhere on the board
Member-E-Stop-sw1-1: J11.1; also elsewhere on the board
Member-Green-Button-2: J6.1; also elsewhere on the board
N/L2: J5.2; also elsewhere on the board

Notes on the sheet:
These screw terminals are broken out for all functions. The terminals are in pairs, and labeled on the board. Bonus mode: if you want to use this whole board as a low-current AC "smart switch" you can attach an interrupted 'Hot' line across J12-1 and J11-3. Just don't exceed the limits of Relay 1-2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
Active Door Control [such as to power a solenoid actvation directly] ***** Used nearly as intended as a tool, follow most labels ***** SW: requires 'set' and 'reset' relays to open/close door --> Jumper shut as labeled: G.btn, R.btn, (both)EStpA, (both)EStpB --> Use G.light as normal to indicate wh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
Stage 3 ||Final Contactor & Screw Terminals
With a separate connection, in parallel to everything else, this will power the stage 3 contactor. A green indicator light is used to show the state of power. The primary E-Stop (sw1) works on this line, to directly cut power to the contactor and by extension the tool. This is mechanically activate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
Many tools will have this jumpered-shut. Only tools that need a second E-Stop in a more reachable place will use this.
This fuse may be unnecessary if powered from 'mains-fused-H/L1'
Use this board as Active and Passive door controller
Putting the main E-Stop here has it as 'close' to the tool as possible. This should makes it less likely to fail because of a self-welded relay. Because it is mechanically linked, this will also activate with 'Member-E-Stop-sw2'
The output fron the S2 relay that controls the Stage 3 contactor.
main E-stop -->
Control for Final Contactor
N-ON switch
aux E-stop -->
Output to control the Contactor, and a light to show the state.
N-ON switch needed for bypass mode
Screw Terminals for all functions
S2 Output -->

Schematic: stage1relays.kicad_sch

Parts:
Bypass-1: Conn_01x02_Female; JST_PH_B2B-PH-K_1x02_P2.00mm_Vertical; JLCPCB Part # C131337
D2: LED; LED_0603_1608Metric; JLCPCB Part # C2286
D3, D4: B160-E3; D_SMA; JLCPCB Part # C24784
PS1: CFM06S050; CFM06S050E; Mouser Part Number 418-CFM06S050-E
R26, R27, R29: 1k; R_0603_1608Metric; JLCPCB Part # C21190
R28, R30: 10k; R_0603_1608Metric; JLCPCB Part # C25804
T3, T4: AO3400A; SOT-23; JLCPCB Part # C427382
relay1, relay2: JQC-3FF/005-1ZS(551); Relay_SPDT_SANYOU_SRD_Series_Form_C; JLCPCB Part # C9221

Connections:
+5V: D3.1 (K), D4.1 (K), PS1.3 (+VOUT), R26.2, relay1.5, relay2.5; also elsewhere on the board
/mainslevelcontrol/stage1relays/dcp2: D4.2 (A), T4.3 (D), relay2.2
GND: Bypass-1.2, D2.1 (K), PS1.4 (-VOUT), R28.2, R30.2, T3.2 (S), T4.2 (S); also elsewhere on the board
Green-Indicator-light-1: PS1.2 (ACL), relay1.3; also elsewhere on the board
Member-E-Stop-aux2-2: PS1.1 (ACN); also elsewhere on the board
unnamed: D2.2 (A), R26.1
unnamed: R27.2, R28.1, T3.1 (G)
unnamed: R29.2, R30.1, T4.1 (G)
read-bypass: Bypass-1.1, D3.2 (A), T3.3 (D), relay1.2; also elsewhere on the board
reset: relay2.4; also elsewhere on the board
reset3v: R29.1; also elsewhere on the board
set3v: R27.1; also elsewhere on the board

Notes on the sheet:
The 'SET' relay allows the tool to be turned on with the additional press of the green button by the human operator. Bypass locks this relay 'ON'
The 'RESET' relay will break the active latch on the Stage 2 relay. This is used as a way to auto shut off the tool - after end of observed current.
need to check these pins...
Relay #1-2 tool timeout [5v coil activation]
Sealed switching power supply, soldered in place. Can accept 90-264VAC to generate 5V, up to 6W. 100mV ripple and 78% efficient, by datasheet.
Stage 1 || Control from 5V & 'set' or 'reset' Stage 2 Latch
Set Relay
Reset Relay
sanity check power LED
Relay1 [NOFF 'set' the Stage 2 relay's Latch] {5VDC coil activation} Relay2 [NON 'reset' the Stage 2 relay's Latch] {5VDC coil activation}
active self-latching of a relay https://electronics.stackexchange.com/questions/223691/self-latching-relay
A 'bypass key' mounted on the case will let anyone with the key use a full hardware-override of the system. This will also be readable by the microcontroller, for feedback.
This stage is responsible for allowing the microcontroller to control the actions of the mains level of power switching.
5V supply from mains (in box)
Relay #1-1 and bypass [5v coil activation]

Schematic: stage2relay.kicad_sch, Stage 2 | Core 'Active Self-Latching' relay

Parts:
F1: Fuse; Fuseholder_Cylinder-5x20mm_Stelvio-Kontek_PTF78_Horizontal_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; JLCPCB Part # C717030
F2: Fuse; Fuseholder_Cylinder-5x20mm_Stelvio-Kontek_PTF78_Horizontal_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
LA1: Lamp
R31: Relay_Omron_MY2-02; relay-Omron-MY2-02
SW2: SW_Push

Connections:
Green-Indicator-light-1: F1.2, R31.9; also elsewhere on the board
Green-Indicator-light-2: R31.8; also elsewhere on the board
H/L1: F1.1; also elsewhere on the board
Member-E-Stop-aux2-2: F2.2; also elsewhere on the board
Member-E-Stop-sw1-1: R31.12; also elsewhere on the board
Member-Green-Button-2: R31.5, R31.13; also elsewhere on the board
unnamed: LA1.1 (-), SW2.2
N/L2: F2.1; also elsewhere on the board
reset: R31.14; also elsewhere on the board

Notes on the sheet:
Connection to mains-fused-H/L1 ==> Regulated by two controllers in logical 'OR' configuration - bypass key (manual activation) - S1-1 'set' relay for SW 'enable'
The previous Tool-Controller design was just this section of the circuit (with simpler Microcontroller connection).
Mains power needs connected here, and will power the whole box. Except, perhaps, the tool. If more exotic power is needed. Labeled on PCB as H/L1 & N/L2 to cover the bases (that both may be live).
S1-2 relay for timeout on tool
'Reset' circuit on Stage 2 relay
Stage 2 || Core Functions run at full 110-230VAC
If there is a Stage 3 relay, then Stage 2 relay can have a lowered switching current -> down to approximately 2amps
The E-Stop light runs at 5V, and is shown here becuase it conceptually makes sense on the sheet. This lamp-to-switch connection is done on the modular E-Stop switches themselves, not any PCB. The middle 'read-E-stop' informs the microcontroller.
N-ON switch
The E-Stop is connected from a 3-wire header: >> 5V goes 'above' the incadescent bulb >> Read goes 'between' E-Stop and switch >> GND goes 'below' switch
N-OFF switch
N-ON switch needed for bypass mode
E-Stop on modular, panel-mount button
aux E-stop -->
forgetful member -->
These are all the ways to 'reset' the Stage 2 relay. [Not including overall loss of power, which also causes reset.] Normally a member will press the red button. But they may also use the E-Stop to temporarily pause function, or the timeout could trigger automatically if programmed correctly...
This Estop is linked to 'Member-E-Stop-sw1' The EStop here (sw2) resets the active self-latch and also blocks the green button from working.
active self-latching of a relay https://electronics.stackexchange.com/questions/223691/self-latching-relay
Fuse Protected Power Inputs
'Set' & 'Latch' circuit on Stage 2 relay
normal tool end -->
main E-stop -->
N-ON switch Many tools will have this jumpered-shut. Only tools that need a second E-Stop in a more reachable place will use this.
Relay 2 [main function] {110VAC or 240VAC coil activation}
In this location, the E-Stop shuts off the tool and resets the active self-latch at the same time. and this works in bypass mode.
Out to Stage 3
Provides the majority of the Member's interface experience
This portion of the circuit allows the Stage 2 Relay to turn on & stay on. When enabled [by ESP32 or Bypass] a person can turn on the relay with the green button. Once activated, the link from relay pin 5_to_13 'latch' the relay on while powered, until reset. The "Can-Turn-On" light will shine if i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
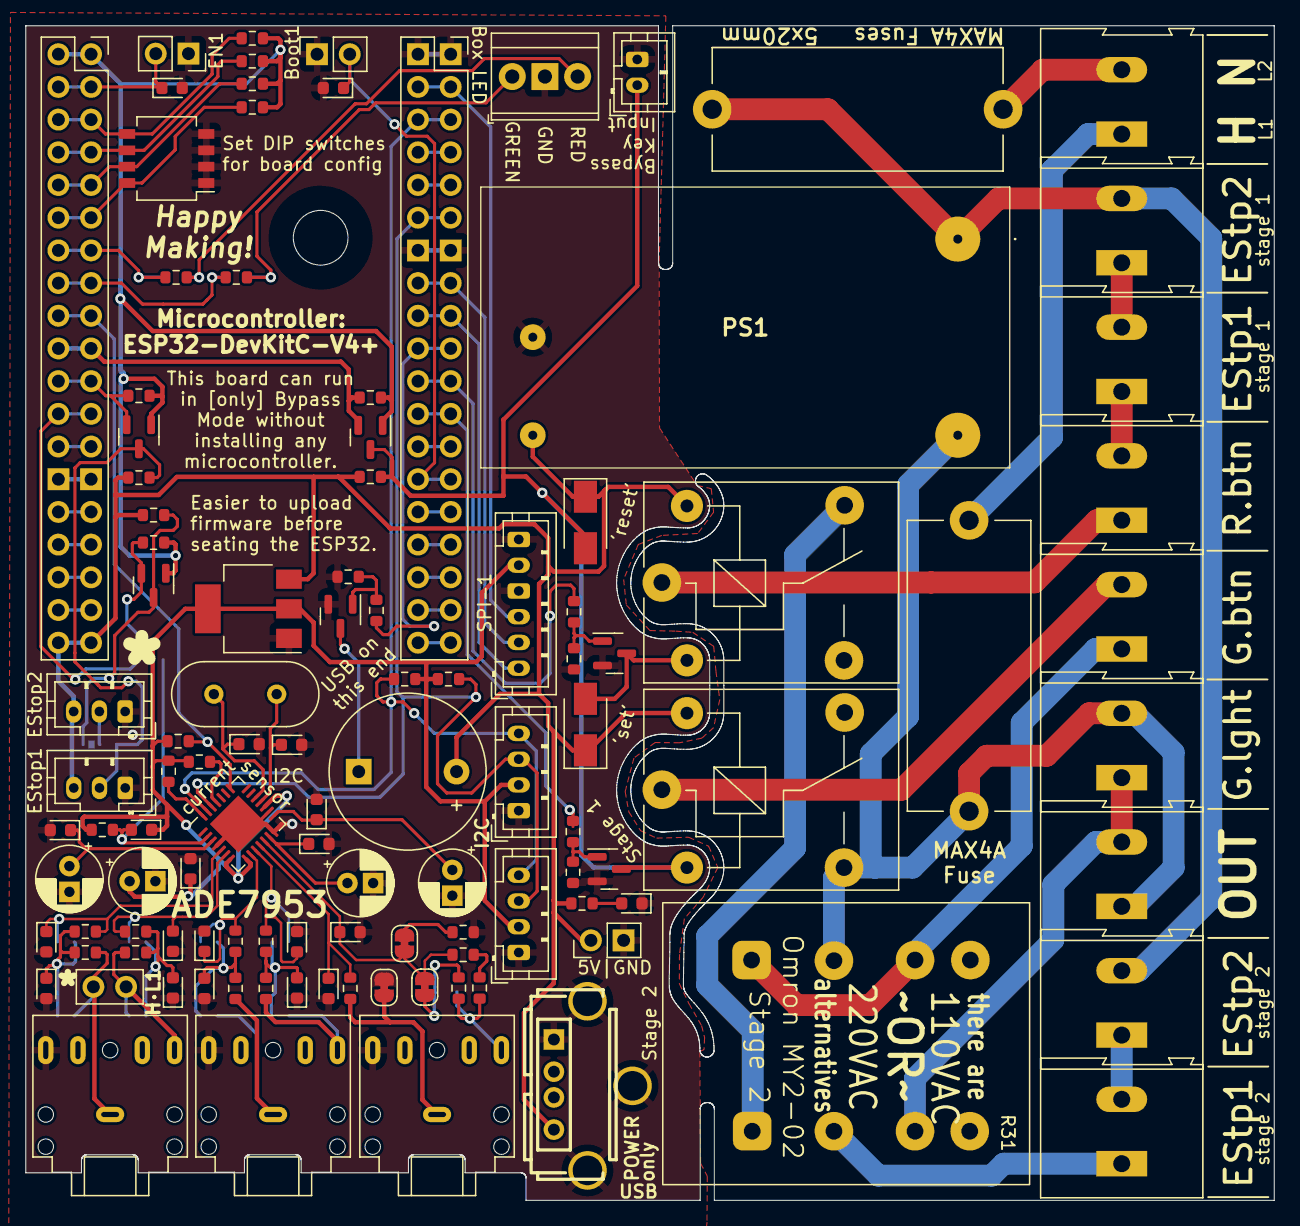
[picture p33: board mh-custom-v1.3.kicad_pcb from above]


Board: 2 copper layers, 97.0 x 91.3 mm, 123 parts (13 on the bottom side), 90 nets.

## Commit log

2022-11-05 design files added
    [CFM06S050-E.stp, ade7953.kicad_sch, breakoutbaords.kicad_sch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]
2022-11-06 rerouted to save space
    [ade7953.kicad_sch, mh-custom-v1.3.kicad_pcb, mh-custom-v1.3.kicad_sch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]
2022-11-06 jumpers added to bottom
    [ade7953.kicad_sch, mh-custom-v1.3.kicad_pcb, mh-custom-v1.3.kicad_sch]
2022-11-06 fixing edges and connecting all pieces
    [ade7953.kicad_sch, lightsounds.kicad_sch, mh-custom-v1.3.kicad_pcb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]
2022-11-07 connections made, style points added. needs double-check
    [mh-custom-v1.3.kicad_pcb]
2022-11-08 finished B silkscreen
    [mh-custom-v1.3.kicad_pcb]
2022-11-08 minor adjustments F Silkscreen
    [mh-custom-v1.3.kicad_pcb]
2022-11-08 updated readme to include KiCAD
2022-12-02 added board renders to readme
2022-12-02 added board renders | edit
2023-01-27 fix(breakoutboards): flipped I2C pins, to conform with common wire colors [on JST connectors]
    [breakoutbaords.kicad_sch]
2023-02-01 close the last ratsnests
    [ade7953.kicad_sch, lightsounds.kicad_sch, mh-custom-v1.3.kicad_pcb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]
2023-02-28 clarify door-activator role || Active & Passive door operation
    [ade7953.kicad_sch, lightsounds.kicad_sch, mh-custom-v1.3.kicad_pcb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]
2023-03-09 fix(board): correct lables for the stage 1 relays
    [mh-custom-v1.3.kicad_pcb]
2023-03-09 fix(board): b.silkscreen updated to show connections for use as a door controller
    [mh-custom-v1.3.kicad_pcb]
2023-04-05 fix(lightsounds): add bypass jumpers for the resistors on the indicator LEDS --> in case there is an indicator with resistors baked-in
    [ade7953.kicad_sch, breakoutbaords.kicad_sch, esp32core.kicad_sch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]
2023-07-18 added stage levels to Estops on F.Silkscreen
    [mh-custom-v1.3.kicad_pcb]
2023-07-18 made EStop Header labels more readable
    [mh-custom-v1.3.kicad_pcb]
2023-07-19 change silkscreen lables for the E-Stop JST connectors, to match large-gauge wiring
    [mh-custom-v1.3.kicad_pcb]
2023-07-27 added the reader-daughter board, from second order at JLCPCB
    [reader-daughter-B_Cu.gbl, reader-daughter-B_Mask.gbs, reader-daughter-B_Paste.gbp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]
2023-07-27 include the BOM files, from gitignore
    [reader-daughter-BOM.csv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]
2023-07-27 added reader-daugheter PDF schematic
2023-07-27 added schematic to documentation
2023-07-27 toolauth-hardware Schematic added
2023-07-27 added tool-controller schematic to documentation
2023-07-27 documentation to include schematics
2023-07-27 update v1.3 schematic documentation
    [ade7953.kicad_sch, breakoutbaords.kicad_sch, esp32core.kicad_sch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]
2023-07-27 relink schematic to new version
2023-07-27 ensure gerbers are updated for reader-daughter board
    [reader-daughter-B_Cu.gbl, reader-daughter-B_Mask.gbs, reader-daughter-B_Paste.gbp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]
2023-07-27 added links to automationdirect.com buttons/lights
2023-07-30 fixes to board, based on Iris' feedback
    [lightsounds.kicad_sch, mh-custom-v1.3.kicad_pcb, mh-custom-v1.3.kicad_sch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]
2023-07-31 remade the 'made-at-makehaven' logo
    [mh-custom-v1.3.kicad_pcb]
2023-07-31 update images for new board version
2023-08-09 reader daughter documentation update
    [mh-custom-v1.3.kicad_pcb]
2023-08-09 led clarity
2023-08-10 updated boards with improved silkscreen and pad-shapes
    [reader-daughter.kicad_pcb, reader-daughter.kicad_sch]
2023-08-10 changed images to fit with new board design
2023-08-13 added note for jumperrs that need cut with ESP32 boards
2023-12-24 add photo documentation to help with wiring the b1p2 boards
